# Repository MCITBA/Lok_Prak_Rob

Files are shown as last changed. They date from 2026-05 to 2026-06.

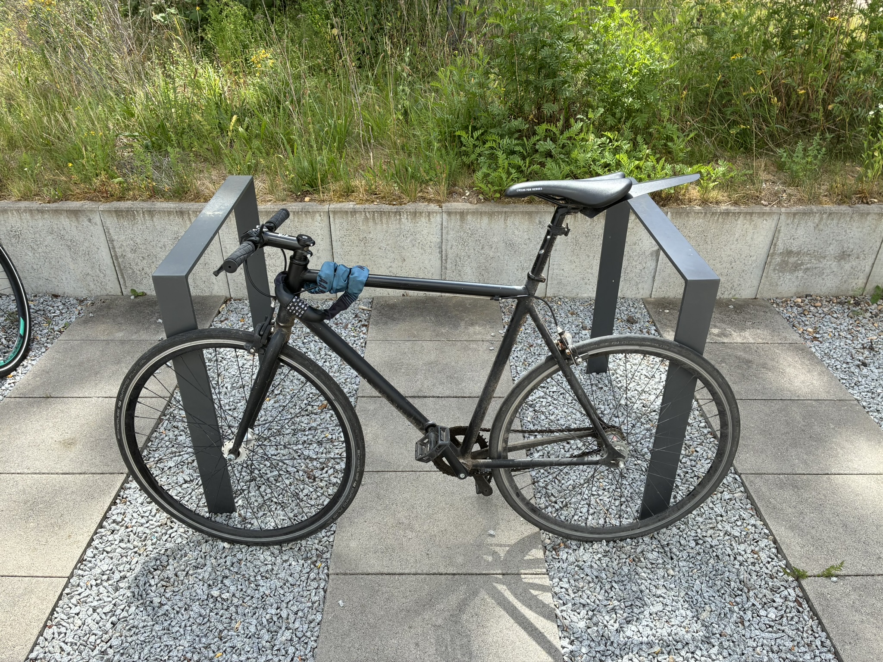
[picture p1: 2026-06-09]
iCloud Fotos/IMG_4484.JPEG

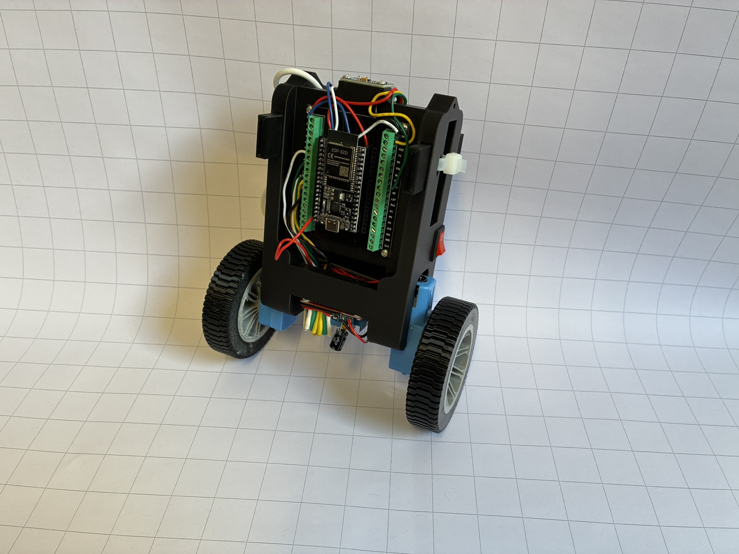
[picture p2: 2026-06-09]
iCloud Fotos/IMG_4480.JPEG

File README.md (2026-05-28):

Werte von KP KI KD  
Text: https://www.overleaf.com/project/6a01d511ccd4f65ef6ab566e  
neuste code version ist: balancing_robot_motors.ino  
Code der potentiel falsche nachrichten foramte der MPU filtert: balance_robot_MPU_fehler  
Sachen die ich brauche:  
u-kürzel, m-nummer  
Name des Fill Material  
foto von: TT-motor, Batterie, Hülle, Rädern, Schalter  
Welche Überstzung beim Motor  
Eckdaten der Baterrie: Volt, A, Ah

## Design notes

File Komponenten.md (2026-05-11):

MPU-6500 (ähnlich zum MPU-6050)
    https://randomnerdtutorials.com/esp32-mpu-6050-accelerometer-gyroscope-arduino/?utm_source=chatgpt.com

    https://github.com/libdriver/mpu6500/blob/main/README_de.md

    https://www.elektronik-kompendium.de/sites/praxis/bauteil_mpu6050-imu.htm

L298N 
    https://randomnerdtutorials.com/esp32-dc-motor-l298n-motor-driver-control-speed-direction/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

Kommunikation
    https://randomnerdtutorials.com/esp32-bluetooth-low-energy-ble-arduino-ide/?utm_source=chatgpt.com

    https://randomnerdtutorials.com/esp32-bluetooth-guide/?utm_source=chatgpt.com

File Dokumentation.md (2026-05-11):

# Ziele / Aufgabe
- Ein Roboter der auf nur zwei Rädern fährt und sich selbstständig aufrecht hält
    - hierfür wird ein PID-Regler verwendet
    - Daten liefert der MPU-6500
- Kommunikation mit einem Handy ermöglichen
    - BLE + entsprechende
    - Austausch von Sensordaten
    - Einstellung der PID-Parameter
        - einfaches Einstellen und Anpassen übers Handy
    - Vorgabe des Soll-Winkels
    - Lenkeinschlag
- Ermöglichen einer Lenkung
    - Ansteuerung ebenfalls über das Smartphone
    - Idee:
        - Soll-PWM für Motor wird "aufgeteilt"
        - prozentual, je nachdem wie stark gelenkt werden soll
- Zusätzliche Herausforderungen
    - wie kann sichergestellt werden, dass der Roboter auch gerade fährt?
        - Verwendung der Beschleunigungswerte?

# Warum haben wir welche Komponenten ausgewählt
## alte Powerbank
- 10.000 mAh
- Output: 2.1 A bei 5V

## ESP32D
- hat bereits eine Antenne verbaut
- ausreichend hohe Taktrate für die Regelung
- läuft auf 5V - passt also zu unserer Powerbank
- Verwendung eines Entwicklungsboards, um den ESP32 am Roboter zu befestigen

## TT-Motor
- ein Motor pro Rad, damit wir lenken können
- müssen für 3V ausgelegt sein (siehe Motortreiber)
- haben bereits ein Getriebe integriert, das ist notwendig um die drehzahl zu verringern

## Motortreiber - L298N
- I2C kompatibel
- Zur Steuerung der Drehgeschwindigkeit und **Drehrichtung**  <--wichtig!
    - H-Brücke
- kann zwei Motoren gleichzeitig ansteuern
- funktioniert auch noch bei 5V *untere Grenze!*
    - Logische Spannung bei 5V und dann über Jumper auch Antriebsspannung
    - interner Spannungsabfall von ca. 2 V (Spannungsabfall an den Transistoren der doppel H-Brücke)

## Gyroskop und Beschleunigungssensor - MPU-6500
- I2C kompatibel
- je drei Achsen
- für 3 bis 5V ausgelegt
- kleines Modul zur Bestimmung der Beschleunigung und der Verdrehung

## Zusätzliche Komponenten
- Schalter
- - gesamten Roboter an/aus schalten
- Smartphone zur Kommunikation 
    - Vorgaben des Sollwinkels
    - Einstellen der Regelparameter 
    - Lenken

## Zusammenfassung
- alle Komponenten laufen mit 5V
- Kommunikation über I2C möglich

# Schaltkreis
- optionale Kondensatoren hinzugefügt

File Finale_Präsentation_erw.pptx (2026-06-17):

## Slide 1

Name - Title of Presentation

The new PowerPoint Slide library is here!
Modern design, many targeted layouts, easy to use.
The new template offers many options for creating presentations with a uniform and modern look.
The following slides offer an ideal basis for beautifully designed presentations. Simply copy complete slides or individual elements from this file.
As of April 23, 2025
The images included are placeholders

## Slide library

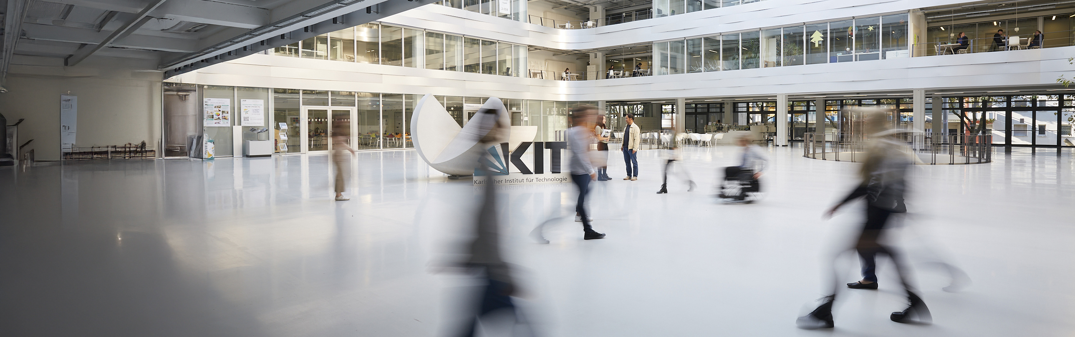
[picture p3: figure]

Designed slides and elements for
easy creation of presentations.

## Design Elements

Highlight Boxes

Lines

Text box

Standard text box
with bullet point

Highlight Box

Highlight Box

Standard Box

Standard Box

Standard text box
with bullet point

Highlight Box

Highlight Box

© Image source top

Highlight Box

1

1

© Image source bottom

Source: I am a dummy text. And I've always been a dummy text

## Design Elements - Pictograms

## Title of the Presentation

Name, Date

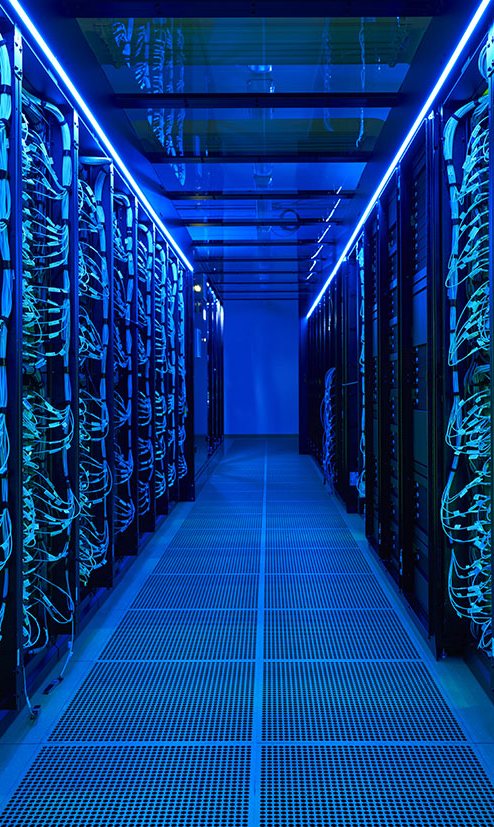
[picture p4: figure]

Placeholder

## Title of the Presentation

Name, Date

Placeholder

## Title of the Presentation

Name, Date

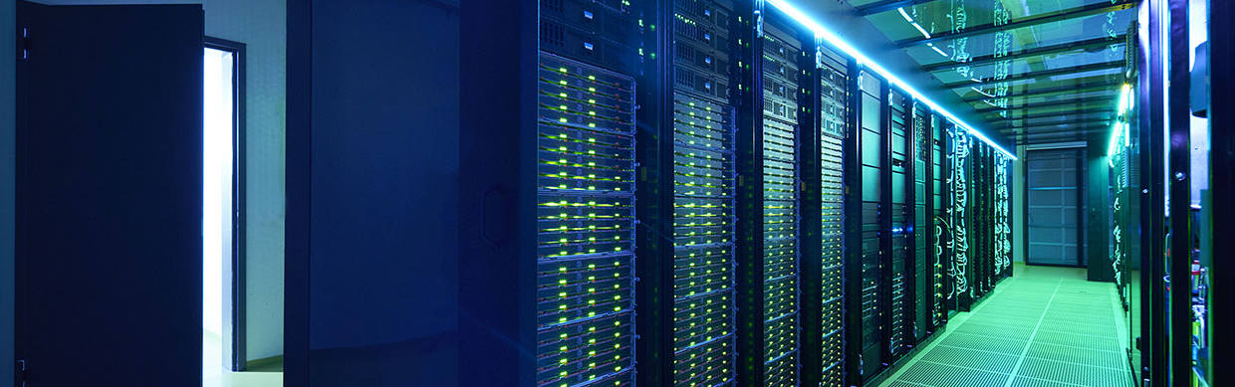
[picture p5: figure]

Placeholder

## Title of the Presentation

Name, Date

Placeholder

## Slide Title

          - I am a dummy copy. And I’ve been a dummy copy since my birth.
- It took me a long time to realize what it means to be a dummy copy: you make no sense. You stand out now and then by being completely out of context.
  - But does that make me a bad copy?
  - I know that I’ll never stand a chance of appearing in the Economist
  - But does that make me any less important? I’m a dummy! But I enjoy being a copy.

## Slide Title

          - I am a dummy copy. And I’ve been a dummy copy since my birth.
- It took me a long time to realize what it means to be a dummy copy: you make no sense. You stand out now and then by being completely out of context.
  - But does that make me a bad copy?
  - I know that I’ll never stand a chance of appearing in the Economist
  - But does that make me any less important? I’m a dummy! But I enjoy being a copy.

          - I am a dummy copy. And I’ve been a dummy copy since my birth.
- It took me a long time to realize what it means to be a dummy copy: you make no sense. You stand out now and then by being completely out of context.
  - But does that make me a bad copy?
  - I know that I’ll never stand a chance of appearing in the Economist
  - But does that make me any less important? I’m a dummy! But I enjoy being a copy.
      - But does that make me any less important? I’m a dummy! But I enjoy being a copy
      - But does that make me any less important? I’m a dummy! But I enjoy being a copy

## Slide Title

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

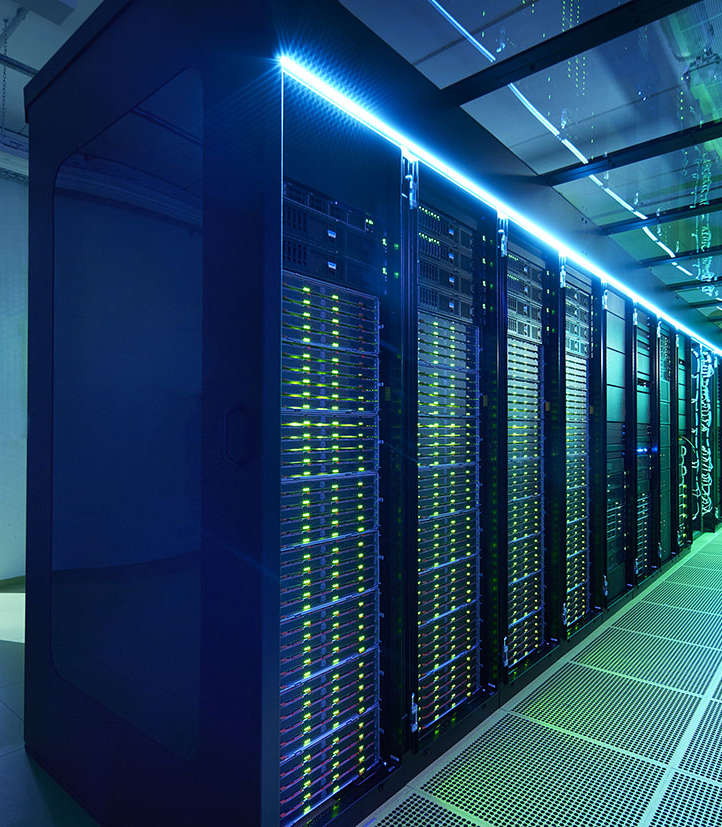
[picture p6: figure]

Placeholder

## Slide Title

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

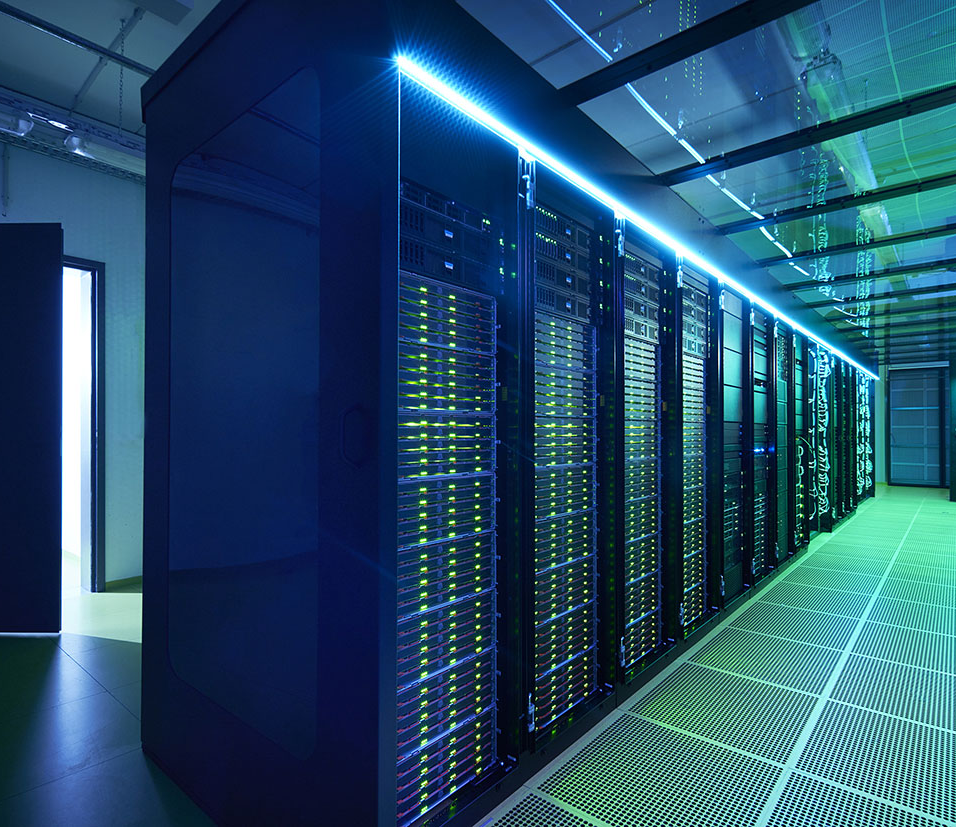
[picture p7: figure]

Placeholder

## Slide Title

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

Placeholder

## Slide Title

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

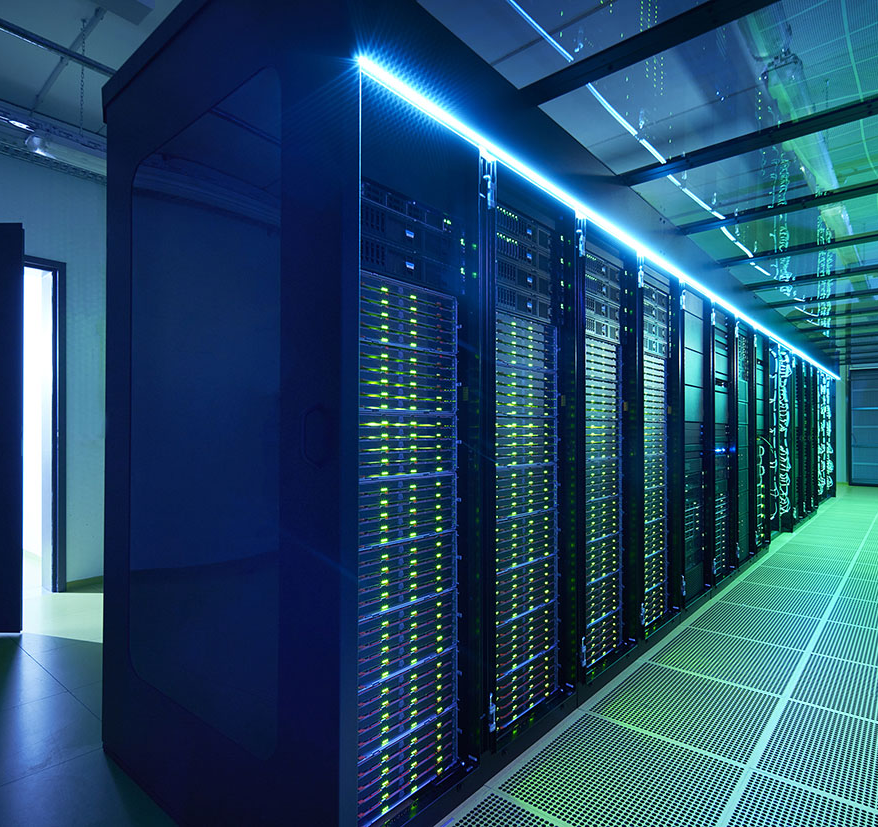
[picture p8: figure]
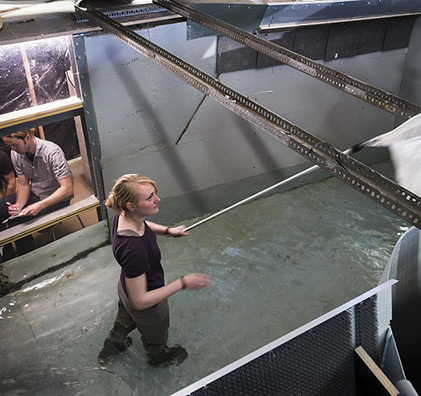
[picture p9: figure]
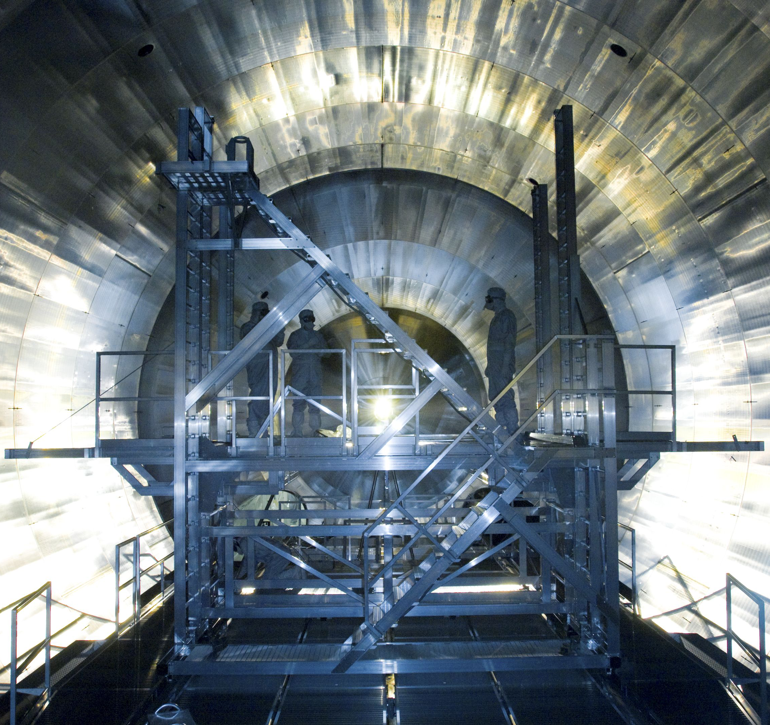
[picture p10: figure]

Placeholder

## Slide Title

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

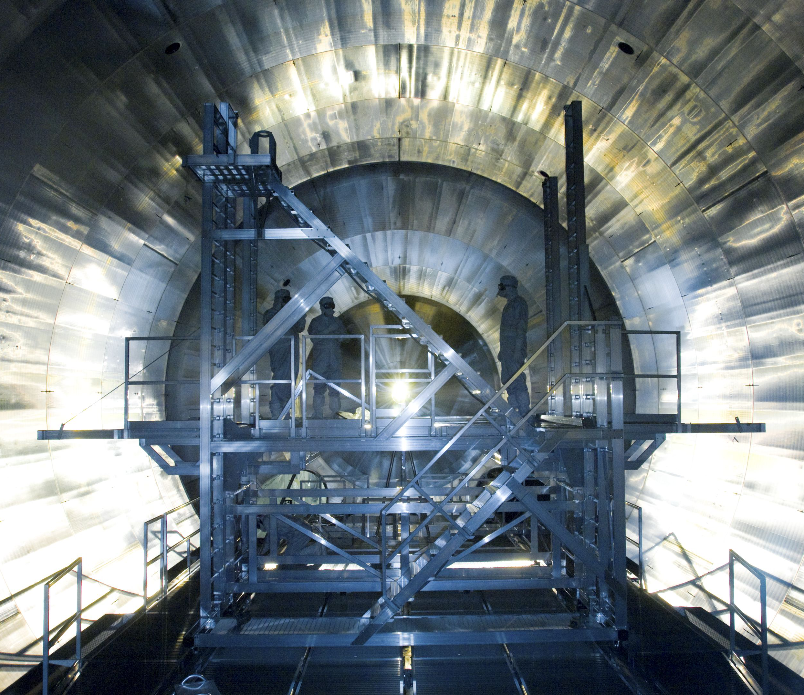
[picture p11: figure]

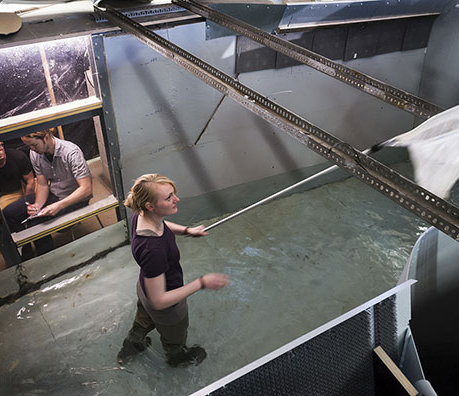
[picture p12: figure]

Placeholder

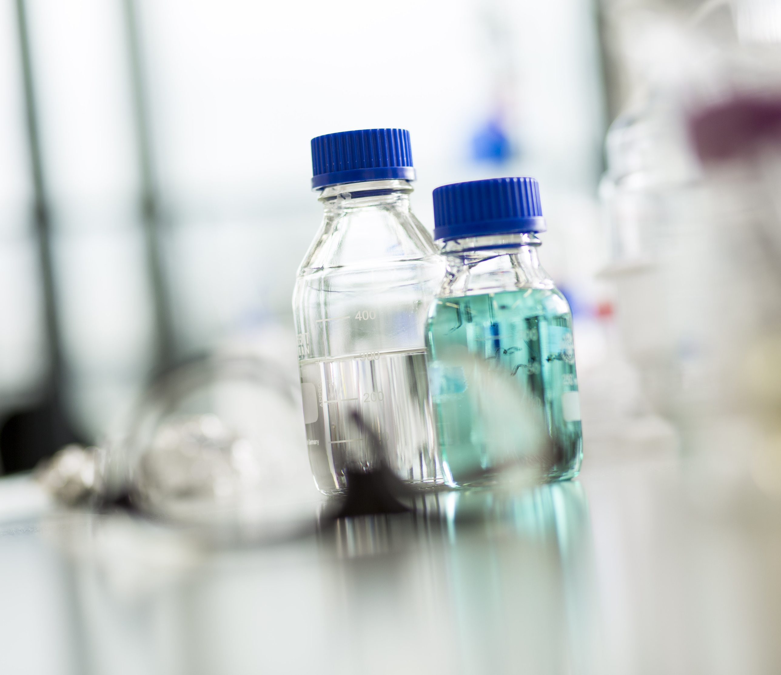
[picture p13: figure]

## Slide Title

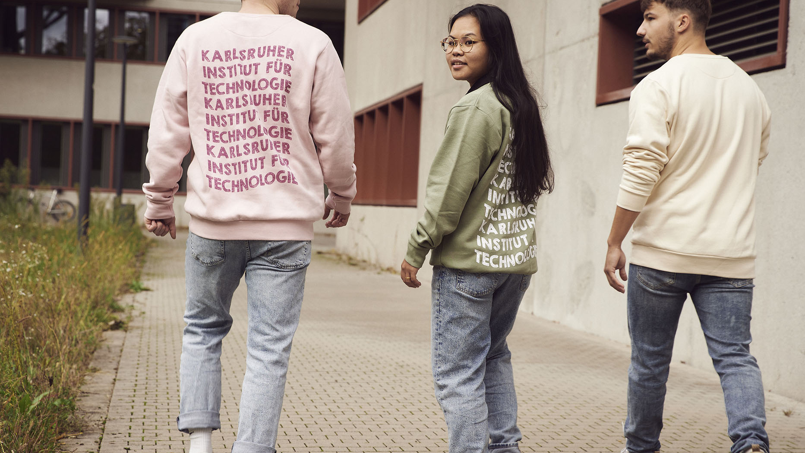
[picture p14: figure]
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

Placeholder

## Slide Title

Source: I am a dummy text. And I've always been a dummy text

## Slide Title

Source: I am a dummy text. And I've always been a dummy text

## Slide Title

Source: I am a dummy text. And I've always been a dummy text

## Slide Title

Source: I am a dummy text. And I've always been a dummy text

## Slide Title

Source: I am a dummy text. And I've always been a dummy text

## Slide Title

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

Source: I am a dummy text. And I've always been a dummy text

## Slide Title

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

Source: I am a dummy text. And I've always been a dummy text

Market shares
65,8 %

## Tables

- After filling the table, it can make sense to highlight important content.
- The best way to do this is to color individual cells, columns or rows.
- Text on colored cells must always be colored white. Totals can be highlighted with a colored line and colored, bold font.

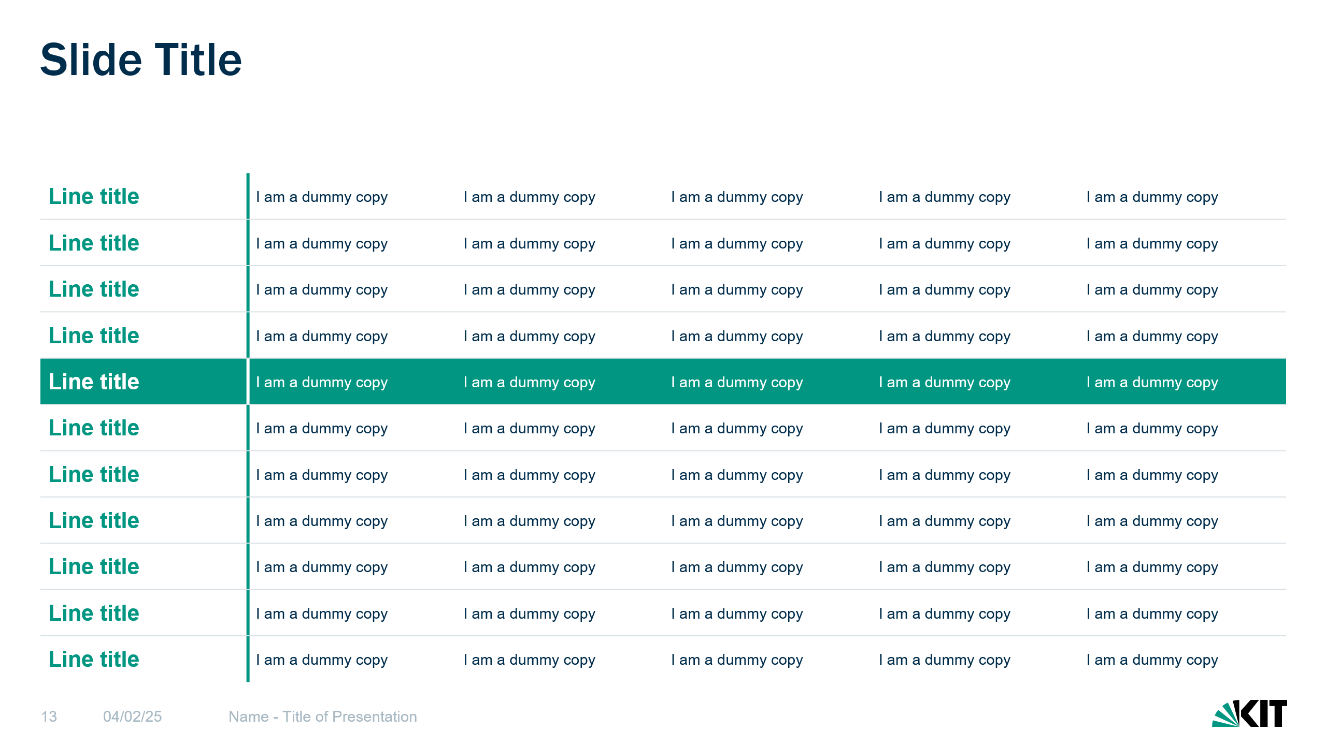
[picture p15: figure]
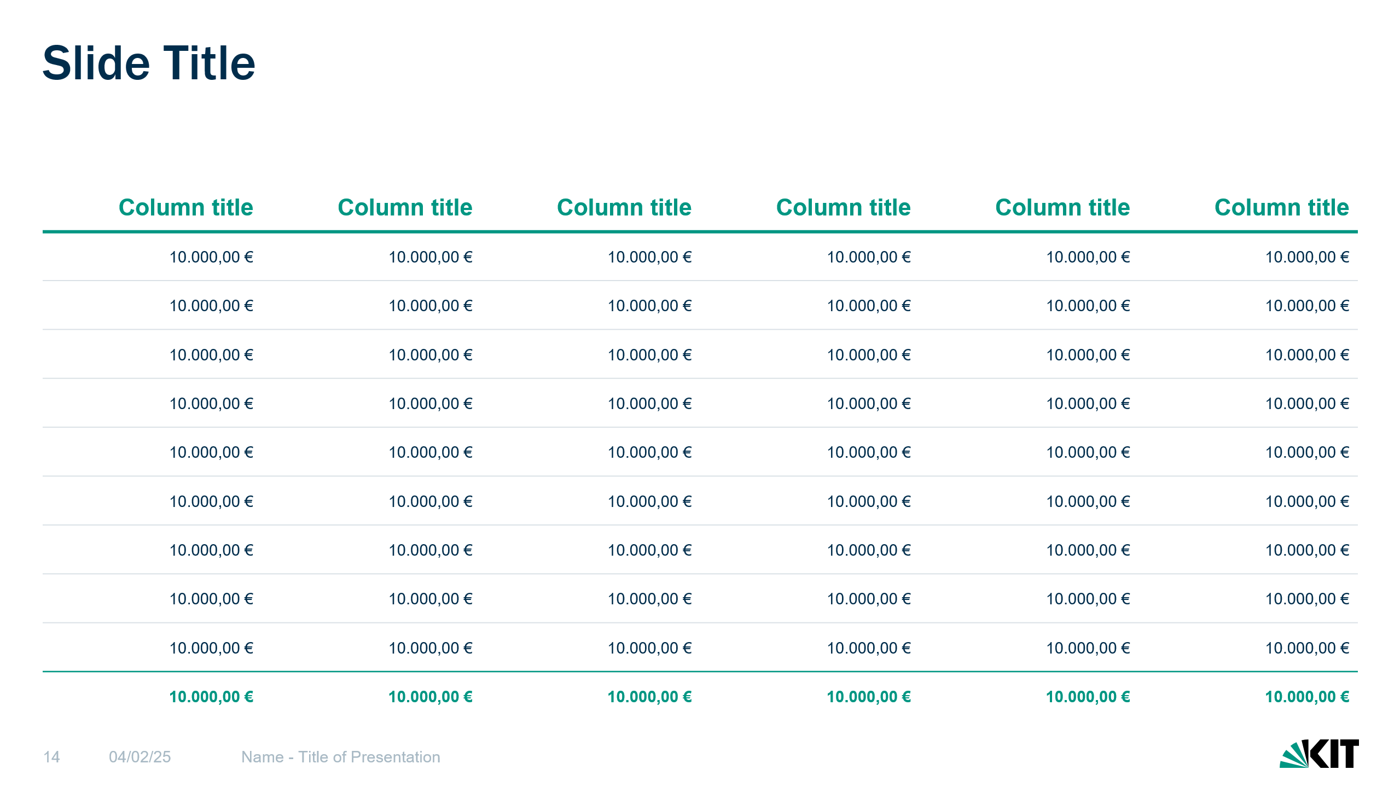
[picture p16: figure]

## Slide Title

Column title | Column title | Column title | Column title | Column title | Column title
I am a dummy copy | I am a dummy copy | I am a dummy copy | I am a dummy copy | I am a dummy copy | I am a dummy copy
I am a dummy copy | I am a dummy copy | I am a dummy copy | I am a dummy copy | I am a dummy copy | I am a dummy copy
I am a dummy copy | I am a dummy copy | I am a dummy copy | I am a dummy copy | I am a dummy copy | I am a dummy copy
I am a dummy copy | I am a dummy copy | I am a dummy copy | I am a dummy copy | I am a dummy copy | I am a dummy copy
I am a dummy copy | I am a dummy copy | I am a dummy copy | I am a dummy copy | I am a dummy copy | I am a dummy copy
I am a dummy copy | I am a dummy copy | I am a dummy copy | I am a dummy copy | I am a dummy copy | I am a dummy copy
I am a dummy copy | I am a dummy copy | I am a dummy copy | I am a dummy copy | I am a dummy copy | I am a dummy copy
I am a dummy copy | I am a dummy copy | I am a dummy copy | I am a dummy copy | I am a dummy copy | I am a dummy copy
I am a dummy copy | I am a dummy copy | I am a dummy copy | I am a dummy copy | I am a dummy copy | I am a dummy copy
I am a dummy copy | I am a dummy copy | I am a dummy copy | I am a dummy copy | I am a dummy copy | I am a dummy copy

## Slide Title

Line title | I am a dummy copy | I am a dummy copy | I am a dummy copy | I am a dummy copy | I am a dummy copy
Line title | I am a dummy copy | I am a dummy copy | I am a dummy copy | I am a dummy copy | I am a dummy copy
Line title | I am a dummy copy | I am a dummy copy | I am a dummy copy | I am a dummy copy | I am a dummy copy
Line title | I am a dummy copy | I am a dummy copy | I am a dummy copy | I am a dummy copy | I am a dummy copy
Line title | I am a dummy copy | I am a dummy copy | I am a dummy copy | I am a dummy copy | I am a dummy copy
Line title | I am a dummy copy | I am a dummy copy | I am a dummy copy | I am a dummy copy | I am a dummy copy
Line title | I am a dummy copy | I am a dummy copy | I am a dummy copy | I am a dummy copy | I am a dummy copy
Line title | I am a dummy copy | I am a dummy copy | I am a dummy copy | I am a dummy copy | I am a dummy copy
Line title | I am a dummy copy | I am a dummy copy | I am a dummy copy | I am a dummy copy | I am a dummy copy
Line title | I am a dummy copy | I am a dummy copy | I am a dummy copy | I am a dummy copy | I am a dummy copy
Line title | I am a dummy copy | I am a dummy copy | I am a dummy copy | I am a dummy copy | I am a dummy copy

## Slide Title

Column title | Column title | Column title | Column title | Column title | Column title
10.000,00 € | 10.000,00 € | 10.000,00 € | 10.000,00 € | 10.000,00 € | 10.000,00 €
10.000,00 € | 10.000,00 € | 10.000,00 € | 10.000,00 € | 10.000,00 € | 10.000,00 €
10.000,00 € | 10.000,00 € | 10.000,00 € | 10.000,00 € | 10.000,00 € | 10.000,00 €
10.000,00 € | 10.000,00 € | 10.000,00 € | 10.000,00 € | 10.000,00 € | 10.000,00 €
10.000,00 € | 10.000,00 € | 10.000,00 € | 10.000,00 € | 10.000,00 € | 10.000,00 €
10.000,00 € | 10.000,00 € | 10.000,00 € | 10.000,00 € | 10.000,00 € | 10.000,00 €
10.000,00 € | 10.000,00 € | 10.000,00 € | 10.000,00 € | 10.000,00 € | 10.000,00 €
10.000,00 € | 10.000,00 € | 10.000,00 € | 10.000,00 € | 10.000,00 € | 10.000,00 €
10.000,00 € | 10.000,00 € | 10.000,00 € | 10.000,00 € | 10.000,00 € | 10.000,00 €
10.000,00 € | 10.000,00 € | 10.000,00 € | 10.000,00 € | 10.000,00 € | 10.000,00 €

## Slide Title

Step 1
I am a dummy copy. And I’ve been a dummy copy since my birth.
It took me a long time to realize what it means to be a dummy copy: you make no sense. You stand out now and then by being completely out of context.

Step 2
I am a dummy copy. And I’ve been a dummy copy since my birth.
It took me a long time to realize what it means to be a dummy copy: you make no sense. You stand out now and then by being completely out of context.

Step 3
I am a dummy copy. And I’ve been a dummy copy since my birth.
It took me a long time to realize what it means to be a dummy copy: you make no sense. You stand out now and then by being completely out of context.

## Slide Title

Step 1
I am a dummy copy.
It took me a long time to realize what it means to be a dummy copy: you make no sense. You stand out now and then by being completely out of context.

Step 2
I am a dummy copy.
It took me a long time to realize what it means to be a dummy copy: you make no sense. You stand out now and then by being completely out of context.

Step 3
I am a dummy copy.
It took me a long time to realize what it means to be a dummy copy: you make no sense. You stand out now and then by being completely out of context.

Step 4
I am a dummy copy.
It took me a long time to realize what it means to be a dummy copy: you make no sense. You stand out now and then by being completely out of context.

## Slide Title

Step 1
I am a dummy copy.
It took me a long time to realize what it means to be a dummy copy.

Step 2
I am a dummy copy.
It took me a long time to realize what it means to be a dummy copy.

Step 3
I am a dummy copy.
It took me a long time to realize what it means to be a dummy copy.

Step 4
I am a dummy copy.
It took me a long time to realize what it means to be a dummy copy.

Step 5
I am a dummy copy.
It took me a long time to realize what it means to be a dummy copy.

Step 6
I am a dummy copy.
It took me a long time to realize what it means to be a dummy copy.

## Slide Title

Step 1
I am a dummy copy. And I’ve been a dummy copy since my birth.

Step 2
I am a dummy copy. And I’ve been a dummy copy since my birth.

Step 3
I am a dummy copy. And I’ve been a dummy copy since my birth.

Step 4
I am a dummy copy. And I’ve been a dummy copy since my birth.

Step 5
I am a dummy copy. And I’ve been a dummy copy since my birth.

Step 6
I am a dummy copy. And I’ve been a dummy copy since my birth.

Step 7
I am a dummy copy. And I’ve been a dummy copy since my birth.

Step 8
I am a dummy copy. And I’ve been a dummy copy since my birth.

## Slide Title

33 %
I am a dummy copy. And I’ve been a dummy copy since
my birth.

33 %
I am a dummy copy. And I’ve been a dummy copy since
my birth.

33 %
I am a dummy copy. And I’ve been a dummy copy since
my birth.

33 %
I am a dummy copy. And I’ve been a dummy copy since
my birth.

## Slide Title

I am a dummy copy. And I’ve been
a dummy copy since my birth.

I am a dummy copy. And I’ve been
a dummy copy since my birth.

I am a dummy copy.
And I’ve been a dummy
copy since my birth.

dummy copy

I am a dummy copy.
And I’ve been a dummy
copy since my birth.

I am a dummy copy. And I’ve been
a dummy copy since my birth.

I am a dummy copy. And I’ve been
a dummy copy since my birth.

## Slide Title

January
2025

February
2025

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

March –
May 2025

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

June –
July 2025

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

August –
October 2025

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

November – December 2025

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

## Slide Title

| CW 1 | CW 2 | CW 3 | CW 4 | CW 5 | CW 6 | CW 7 | CW 8 | CW 8 | CW 10 | CW 11 | CW 12
Dummy copy
Dummy copy
Dummy copy
Dummy copy
Dummy copy
Dummy copy
Dummy copy
Dummy copy
Dummy copy
Dummy copy

Legend

Legend

Legend

## Slide Title

Name
Position, title or function

Name
Position, title or function

Name
Position, title or function

Name
Position, title or function

Name
Position, title or function

Name
Position, title or function

Name
Position, title or function

Name
Position, title or function

Name
Position, title or function

Name
Position, title or function

Name
Position, title or function

Name
Position, title or function

Name
Position, title or function

Name
Position, title or function

Name
Position, title or function

Name
Position, title or function

Name
Position, title or function

Name
Position, title or function

Name
Position, title or function

Name
Position, title or function

Name
Position, title or function

Name
Position, title or function

Name
Position, title or function

Name
Position, title or function

## Slide Title

Name

Name

Name

Name
Position, title or function

Name
Position, title or function

Name
Position, title or function

Name
Position, title or function

Name
Position, title or function

Name
Position, title or function

Name
Position, title or function

Name
Position, title or function

Name
Position, title or function

Name
Position, title or function

Name
Position, title or function

Name
Position, title or function

Name
Position, title or function

Name
Position, title or function

Name
Position, title or function

Name
Position, title or function

Name
Position, title or function

Name
Position, title or function

Name
Position, title or function

Name
Position, title or function

Name
Position, title or function

Name
Position, title or function

Name
Position, title or function

Name
Position, title or function

Name
Position, title or function

Name
Position, title or function

Name
Position, title or function

Name
Position, title or function

Name
Position, title or function

Name
Position, title or function

Name
Position, title or function

## Slide Title

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

Dummy copy

Dummy copy

Dummy copy

Karlsruhe

Dummy copy

Dummy copy

Dummy copy

Karlsruhe

## Contact

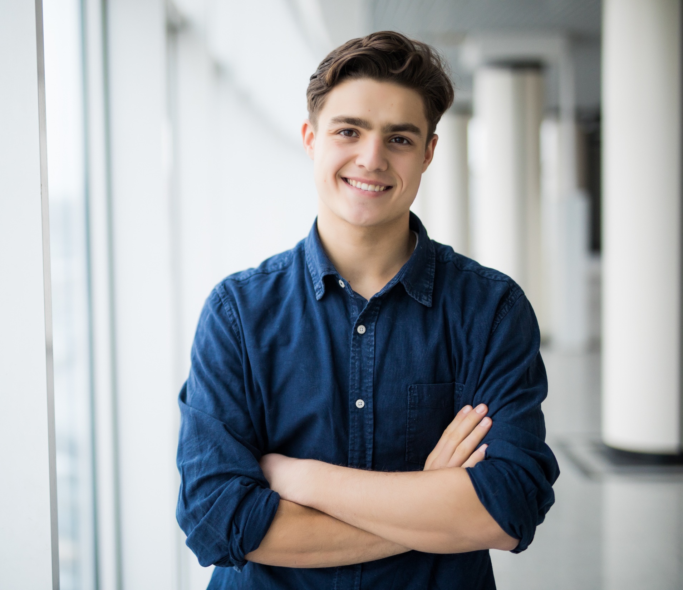
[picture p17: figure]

Placeholder

- Name
- Position, title or function
- +49 000 1234567
- info@kit.edu
- Karlsruher Institut für Technologie
- Kaiserstraße 12 76131 Karlsruhe Germany

## Team

- Name
- Position, title or function

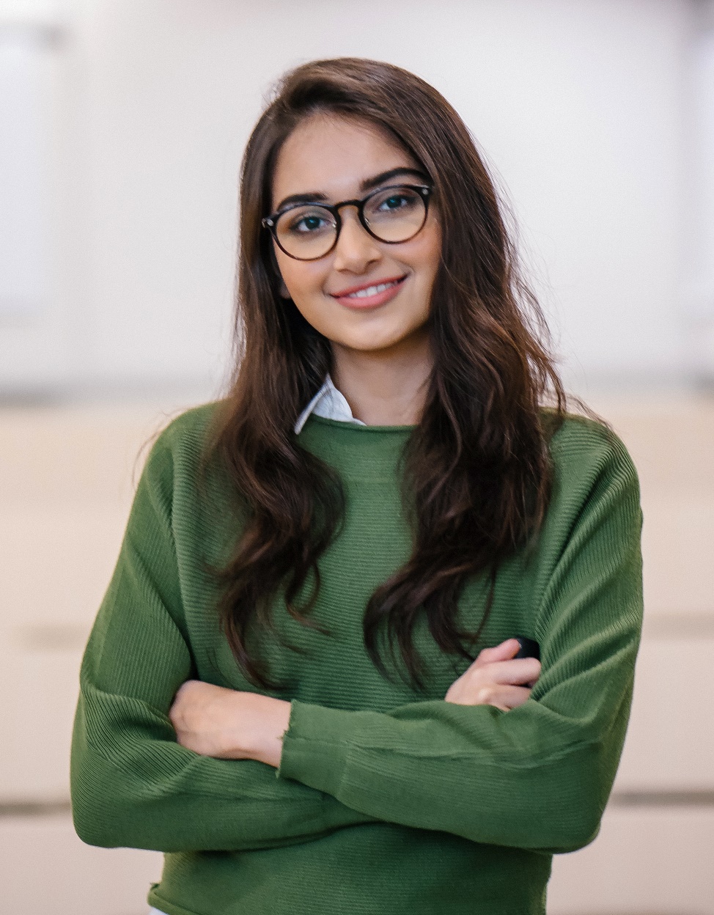
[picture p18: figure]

- Name
- Position, title or function

- Name
- Position, title or function

- Name
- Position, title or function

Placeholder

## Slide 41

## Selbstbalancierender Roboter

Jan Fritze
Marius Carrier

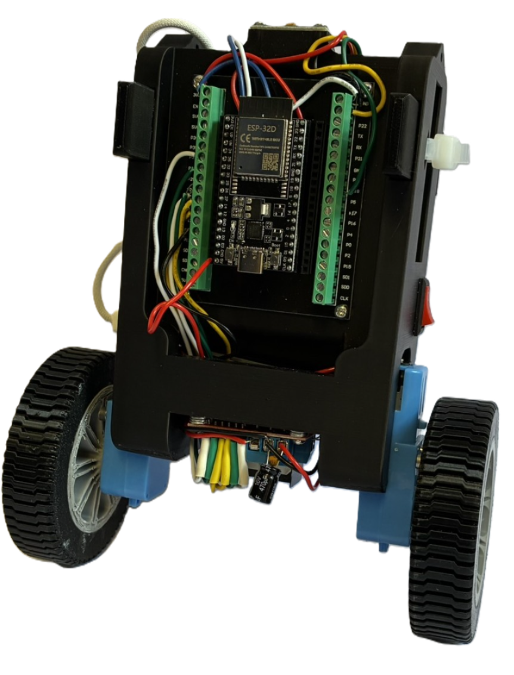
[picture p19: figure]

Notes: Der Roboter verhält sich wie ein inverses Pendel. Da sein Schwerpunkt oberhalb der Radachse liegt, würde er ohne aktive Regelung umfallen.
Deshalb muss eine erkannte Neigung unmittelbar durch eine passende Radbewegung ausgeglichen werden.
Kippt der Roboter nach vorne oder hinten, erkennt der Roboter diese Bewegung und berechnet daraus ein Motorsignal, sodass die Räder in Richtung der Kippbewegung fahren.
Dadurch wird der Aufstandspunkt unter den Schwerpunkt verschoben und der Roboter kann sich wieder aufrichten

## Gliederung

- Aufbau und technische Umsetzung
  - Komponentenauswahl
  - Schaltplan
1. Programmierung
  - IMU
  - Regelkreis
  - Motorsteuerung
  - Live-Tuning
- Ergebnisse
- Ausblick

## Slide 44

M. Carrier J. Fritze – Selbstbalancierender Roboter

Aufbau und technische Umsetzung

## Komponentenauswahl

- ESP32D als zentrale Steuereinheit
  - Ausreichende Rechenleistung und integriertes WLAN
- MPU-6500 zur Winkelmessung
  - Misst Beschleunigung und Winkelgeschwindigkeit
L298N-Motortreiber
  - Ermöglicht die Ansteuerung der Motoren, da der ESP32D die benötigten Motorströme nicht direkt liefern kann
  - H-Brücke ermöglicht Umpolarisierung der Motorenspannung
- Motoren
  - Motoren mit 90:1-Übersetzung für niedrigere Drehzahl

Bauteile
ESP32D
TT-Motor
MPU-6500
L298N
Powerbank
NTC 5D-7
Schalter
ELKO 470
104 Keramikkondensator
PD-Trigger

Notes: Hier seht ihr eine List aller Elektrischen Bauteile
Wir werdend jetzt im laufe der Präsentation, der Grund für die Auswahl der Komponenten sowie deren Wirkung erklären
Anfangen tue ich mit dem prinzipiellen Aufbau
ESP32D ist wie das ESP32 nur das es bereits eine integrierte Antenne hat.
Das haben wir ausgewählt, weil der eigentliche Steuerungsalgorithmus, nicht sonderlich komplex ist
Jedoch brauchen wir die WLAN-Funktion wie wir später zeigen werden
Um kippen zu registrieren nutzen wir den MPU-6500
Die L298N ist sehr wichtig, für die Nutzung der Motoren, da weder kann die ESP32D die nötigen Motorströme liefern, um die Motoren anzutreiben, noch könnte er die Spannung umpolarisieren um die Richtung der Motoren zu wechseln
Für die Motoren haben wir uns für Motoren mit einer Übersetzung von 90:1 entschieden, was uns eine feine Regulierung der Umdrehungen erlaubt

## Das Konzept

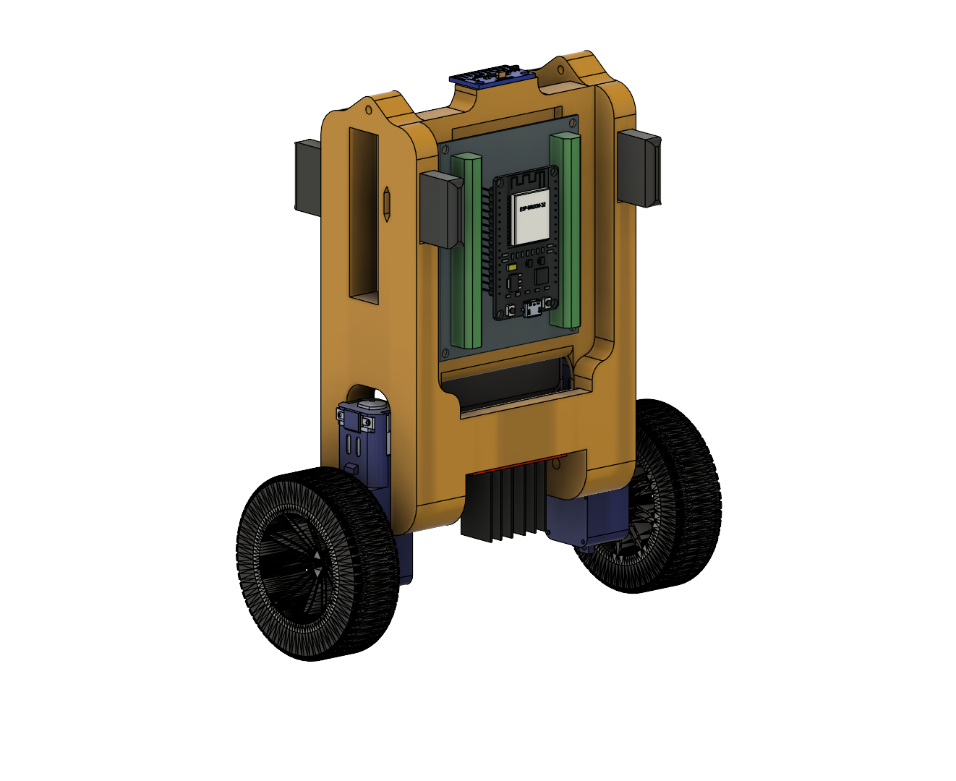
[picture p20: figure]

## Schaltplan und Energieversorgung

- Powerbank als Spannungsquelle
  - Kann 5 oder 9 Volt liefern
  - PD-Trigger fordert 9 Volt an
- L298N als zentraler Leistungsknoten
  - Zwei Spannungslevel
      - Interner Spannungsregler: 5 V für Logik
      - 9 V direkt für Motoren
ESP32 über 5 V Ausgang des L298N
    - Gemeinsame Masse
MPU-6500
    - Über 3,3 V des ESP32 versorgt
Platzsparendes Design
  - Kombination aus Spannungswandler und Motoransteuerung
  - Verzicht auf Step Down Converter

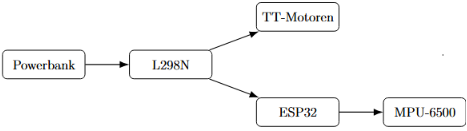
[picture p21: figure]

## Schaltplan und Energieversorgung

Kondensatoren zur Spannungsstabilisierung
  - 100-nF Keramikkondensator:
        - Kompensiert hochfrequente Störungen
    - 470-µF Elektrolytkondensator:
      - Gleicht kurzzeitige Spannungseinbrüche bei Laständerungen aus
Problem mit Kondensatoren
  - Kondensatoren beim Einschalten zunächst ungeladen
  - Verhält sich kurzzeitig wie ein Kurzschluss
  - Hoher Einschaltstrom
NTC zur Begrenzung des Einschaltstroms
  - NTC 5D-7 in kaltem Zustand Nominalwiderstand von 5 Ohm
  - Erwärmt sich nach dem Einschalten
      - Widerstand sinkt stark ab → geringer Spannungsabfall während des Betriebs
Robusterer Betrieb
  - Verringern Risiko von Spannungseinbrüchen und Fehlfunktionen des ESP32

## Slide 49

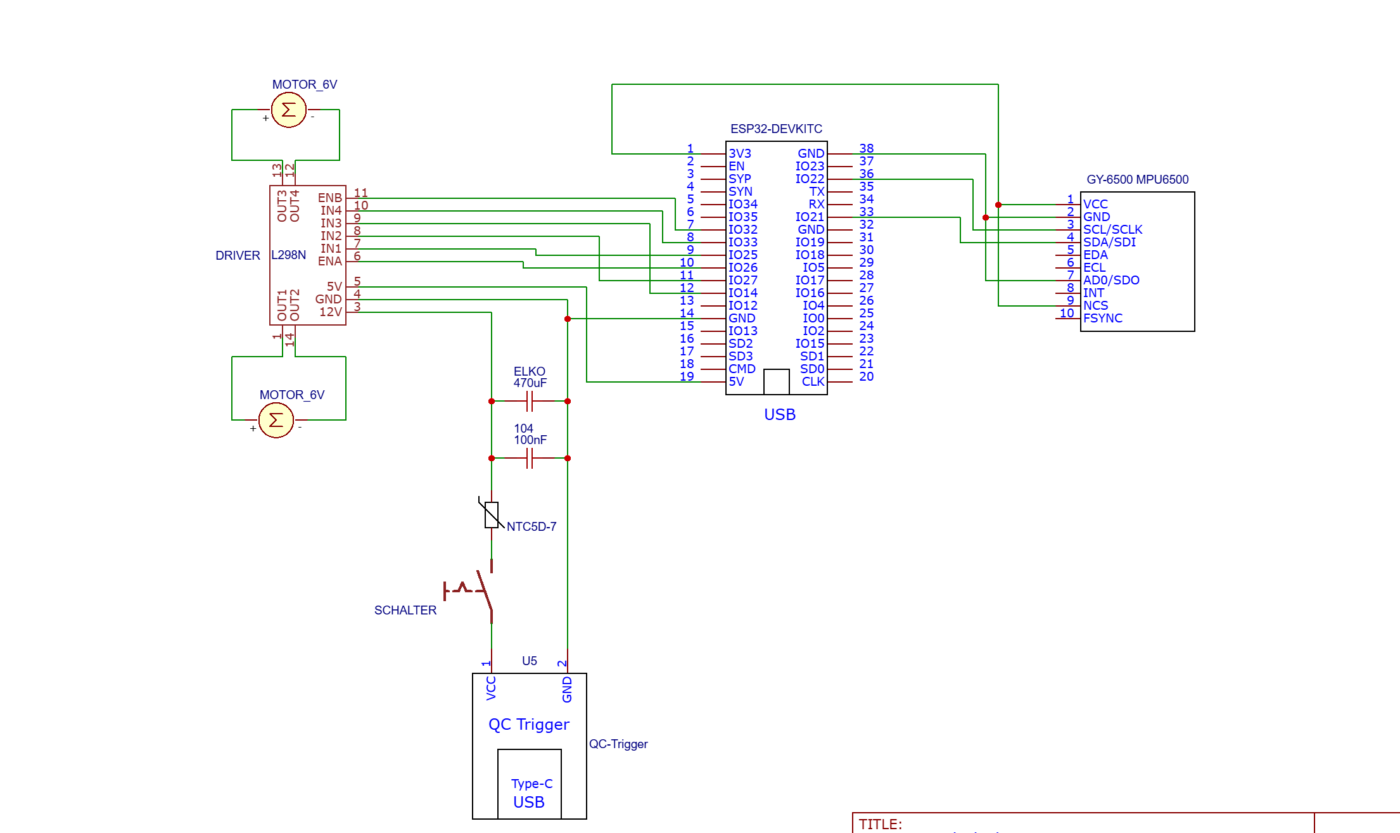
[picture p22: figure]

## Der fertige Roboter

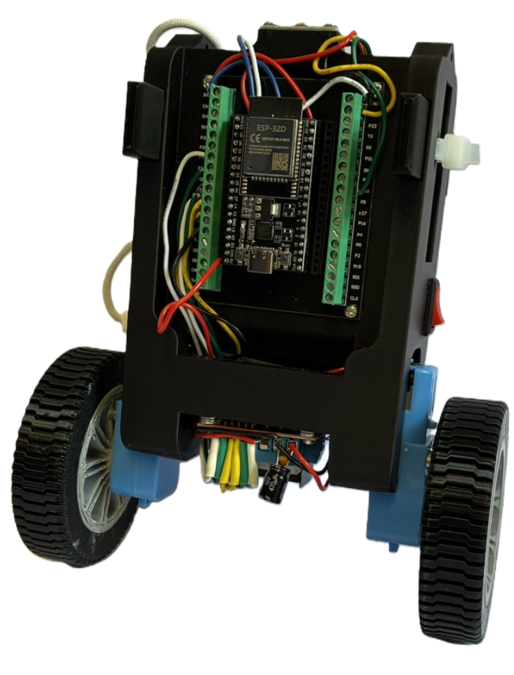
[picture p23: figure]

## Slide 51

M. Carrier J. Fritze -- Selbstbalancierender Roboter

Programmierung

## Programmierung

          - Messung und Kalibrierung des Neigungswinkels
  - Der MPU-6500 erfasst dafür Beschleunigung und Winkelgeschwindigkeit.
  - Der Beschleunigungssensor liefert einen stabilen Referenzwinkel, reagiert aber empfindlich auf Vibrationen und Bewegungen.
  - Das Gyroskop erkennt schnelle Winkeländerungen, ist jedoch langfristig driftanfällig.
  - Ein Komplementärfilter kombiniert beide Signale zu einem schnellen und stabilen Winkelwert.
  - Vor dem Regelbetrieb wird das Gyroskop mit 500 Messungen kalibriert.
  - Tiefpassfilter um Rauschen zu minimieren

M. Carrier J. Fritze – Selbstbalancierender Roboter

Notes: Der Beschleunigungssensor misst die Beschleunigung des Roboters und kann dadurch die Richtung der Erdbeschleunigung erfassen.
Aus dieser Richtung lässt sich ein Neigungswinkel berechnen.
Dieser Winkel ist langfristig stabil, wird jedoch durch Bewegungen, Vibrationen und Beschleunigungen des Roboters gestört.
Das Gyroskop misst dagegen die Winkelgeschwindigkeit.
Durch Integration dieser Winkelgeschwindigkeit über die Zeit kann die Änderung des Winkels sehr schnell erfasst werden.
Dieser Wert eignet sich daher besonders gut für schnelle Bewegungen.
Gyroskops hat jedoch Drift.
Kleine Messfehler werden bei der Integration über die Zeit aufsummiert, wodurch der berechnete Winkel langsam vom tatsächlichen Winkel abweicht.
Komplementärfilter:
Winkel überwiegend aus der Winkelgeschwindigkeit des Gyroskops berechnet und durch den Winkel aus dem Beschleunigungssensor korrigiert.
Der Gyroskopanteil sorgt somit für eine schnelle Reaktion, während der Beschleunigungssensor den Winkel langfristig stabilisiert.
Vor dem Regelbetrieb wird das Gyroskop kalibriert.
Dafür muss der Roboter beim Einschalten ruhig gehalten werden.
Während der Kalibrierung werden 500 Messwerte aufgenommen und gemittelt, um so den Gyroskop-Offset zu bestimmt.
Dieser Offset beschreibt den Messfehler des Gyroskops im ruhenden Zustand und wird anschließend von den weiteren Messwerten abgezogen.
Winkelgeschwindigkeit wird außerdem tiefpassgefiltert, um Messrauschen und schnelle Sprünge im Signal zu reduzieren.

## Programmierung

          - Berechnung der Stellgröße mit dem PID-Regler
  - Grundlage ist der Regelfehler zwischen Sollwinkel und gemessenem Istwinkel.
  - Der PID-Regler setzt sich aus drei Anteilen zusammen: Rückstellung, Korrektur bleibender Abweichungen und Dämpfung schneller Bewegungen.
  - Bei größeren Winkelfehlern wird der P-Anteil ab 7° zusätzlich progressiv verstärkt.
  - So reagiert der Roboter bei kleinen Auslenkungen weich, bei kritischen Schieflagen aber deutlich stärker.
  - Die Stellgröße wird abschließend auf den zulässigen PWM-Bereich begrenzt.

M. Carrier J. Fritze – Selbstbalancierender Roboter

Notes: Zur Regelung nutzen wir einen PID-Regler
Unser Eingangswert ist die Istwinkel und user Fehler ist die Differenz zwischen Soll und Ist winkel
Um die Anteile nochmal zu überfliegen, haben wir hier den linearen Rückstellungswert, Korrektur bleibender Abweichungen und Dämpfung schneller Bewegungen.
Da das Kippmoment des Roboters jedoch nicht, linear ist, haben wir ab 7° ebenfalls einen nicht linearen Korrektur Term eingesetzt.
Dies erlaubt uns bei kleinen Auslenkung fein zu justieren während wir gleichzeitig bei großen Auslenkung, große Korrektur Möglichkeiten haben
Damit die Ergebnisse im Definiertenbereich bleiben, wird die Ausgabe des PWM-Reglers auf -/+ 25 beschränkt

## Programmierung

          - Einfluss der Regelungsfrequenz und PWM-Frequenz
Regelkreis – 200 Hz (berechnet alle 5 ms einen neuen Motorbefehl)
    - Hohe Regelungsfrequenz ermöglicht schnelle Reaktion
    - Zu hohe Frequenzen
      - verstärken Messrauschen
      - können von Motoren mechanisch nicht sinnvoll umgesetzt werden
PWM-Frequenz – 200 Hz
    - Legt fest, wie schnell das Motorsignal ein- und ausgeschaltet wird
    - Bei 200 Hz entstehen längere Impulse
      - Erleichtern das Anlaufen kleiner Gleichstrommotoren
Wahl der Frequenzen
    - Kompromiss zwischen sicherem Anlauf, ruhigem Motorlauf und hörbarem Motorgeräusch

M. Carrier J. Fritze – Selbstbalancierender Roboter

## Programmierung

- Motoransteuerung - Probleme
- Mechanisches Getriebespiel (Backlash):
- ca. ± 2° Leerlauf um Totpunkt
- kleine Korrektursignale laufen ins Leere
- Hohes Losbrechmoment:
- Hohe innere Reibung
- Motoren laufen erst ab einem PWM-Wert von ca. 80 bis 100 an
- Konsequenz:
- klassische, lineare PID-Regelung versagt im Nahbereich des Nullpunkts
  - Kleine Steuersignale → Motoren bewegen sich nicht

M. Carrier J. Fritze – Selbstbalancierender Roboter

## Programmierung

- Motoransteuerung - Lösungsstrategien
- Maßnahme 1: Stufenförmige Mindest-PWM
- Künstliche Anhebung des minimalen Stellsignals knapp über die Haftreibungsgrenze
- Verhindert das träge, unkorrigierte Umkippen des Roboters bei minimalen Winkelfehlern
  - Allerdings: Ruckartiges Anfahren und hohe Mindestdrehzahl
- Maßnahme 2: Dynamische Kickstart-Logik
- Beim Anfahren der Motoren
  - Bei abruptem Richtungswechsel oder aus dem Stillstand
- Für genau 7 Zyklen: mit voller Mindest-PWM angesteuert
  - Mechanisches Spiel im Getriebe wird instantan übersprungen und das Losbrechmoment sofort überwunden
- Danach: Ansteuerung mit niedrigerem PWM-Wert möglich (40 bis 50)
- Ermöglicht geringere Drehzahlen und feinfühligeres Einregeln der Ruhelage

M. Carrier J. Fritze – Selbstbalancierender Roboter

## Programmierung

- Motoransteuerung - Ergebnis
- Ergebnis: Verbesserung der Systemdynamik
- Haftreibung überwinden
- Realisierung geringerer Drehzahlen
- Sicherheitsabschaltung
- Bei Überschreiten eines Fehlers von 30° werden die Motoren abgeschaltet

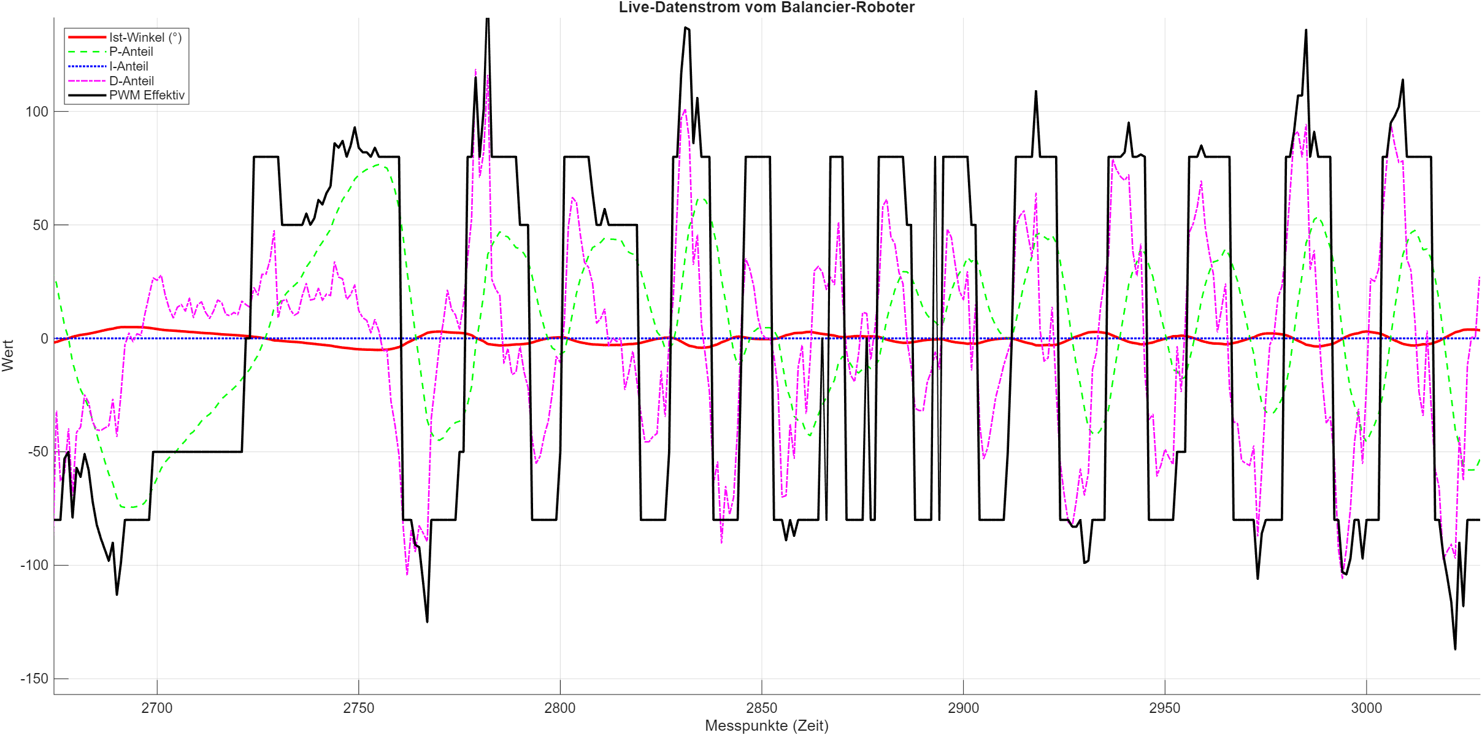
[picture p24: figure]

M. Carrier J. Fritze – Selbstbalancierender Roboter

## Programmierung

          - Live-Tuning
  - Der ESP32D stellt einen Webserver bereit, der über einen Browser aufgerufen werden kann
  - Für sparsamen Ressourcenumgang wird im Hauptloop nur überprüft ob eine Veränderung vorgenommen wurde
  - Vorteile:
      - Um den tatsächlichen Schwerpunkt zu finden wird das Live-Tuning benötigt
      - Ohne Live-Tuning wäre die richtige Kalibrierung schwerer umsetzbar
      - Ermöglicht eine schnellere Anpassung der Parameter, wodurch die Auswirkungen der Änderungen direkt sichtbarer werden
      - Zeitersparnis, da das Programm nach Parameteränderungen nicht erneut geflasht werden muss

M. Carrier J. Fritze – Selbstbalancierender Roboter

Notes: Wie ich am anfang erwähnt hatte nutzen wir die WLAN möglichkeit des ESP32D.
Der nutzen sieht wie folgt aus, das ESP32D erstellt einen Webserver, auf dem sich der User mit einem Notmalen Web browser einwählen kann
Hier können die daten dann live verändert werden, wo bei die Werte nicht jedesmal im loop durchgegangen werden, sondern im Hauptloop nur überprüft wird, ob werte verändert wurden
Vorteile:
Während die Kalibierung sehr nett ist, ist der Schwerpunkt des Roboters überhaupt nicht bei 0°
Was wir also machen, ist den Robtor in seinen Schwerpunkt bringen, der Schwerpunkt über die Anzeige Ablesen, und dann mit dem Angel offset den Sollwinkel anpassen
Dies wäre ohne Live Anpassung nicht machbar, weil jedesmal wenn wir flushen die Kalibierung ein bisschen anders ist und dementsprechend eine Kalibierung auf dem Laptop überhaupt nicht möglich wäre
Außerdem hat uns dies, bei der Parameterfindung geholfen, da wir die Parameter verändern konten und dann live mit verfolgen konnten, welchen einfluss dies auf das Verhalten des Roboters hatte
Auch abesehen von der verbesserten Wahrnebarkeit der Parameterveränderungen war es auch eine Große Zeitersparniss das ESP32D nicht für jeder änderung neu flushen zumüssen

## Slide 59

Ergebnisse

## Regelungstechnische Analyse mittels MATLAB

- Serielle Datenpipeline zur Regelanalyse aufgebaut
- Ausgabe der unskalierten PID-Anteile (P, I, D) und des Stellsignals u(t)
- Synchrone UART-Übertragung mit 200 Hz Schleifenfrequenz
- Grafische Auswertung der Systemantworten in MATLAB
- Unterstützung bei der Optimierung der Regelparameter
- Präzise Identifikation und Isolation komplexer Regelfehler
- Daten für spätere Analyse als CSV gespeichert

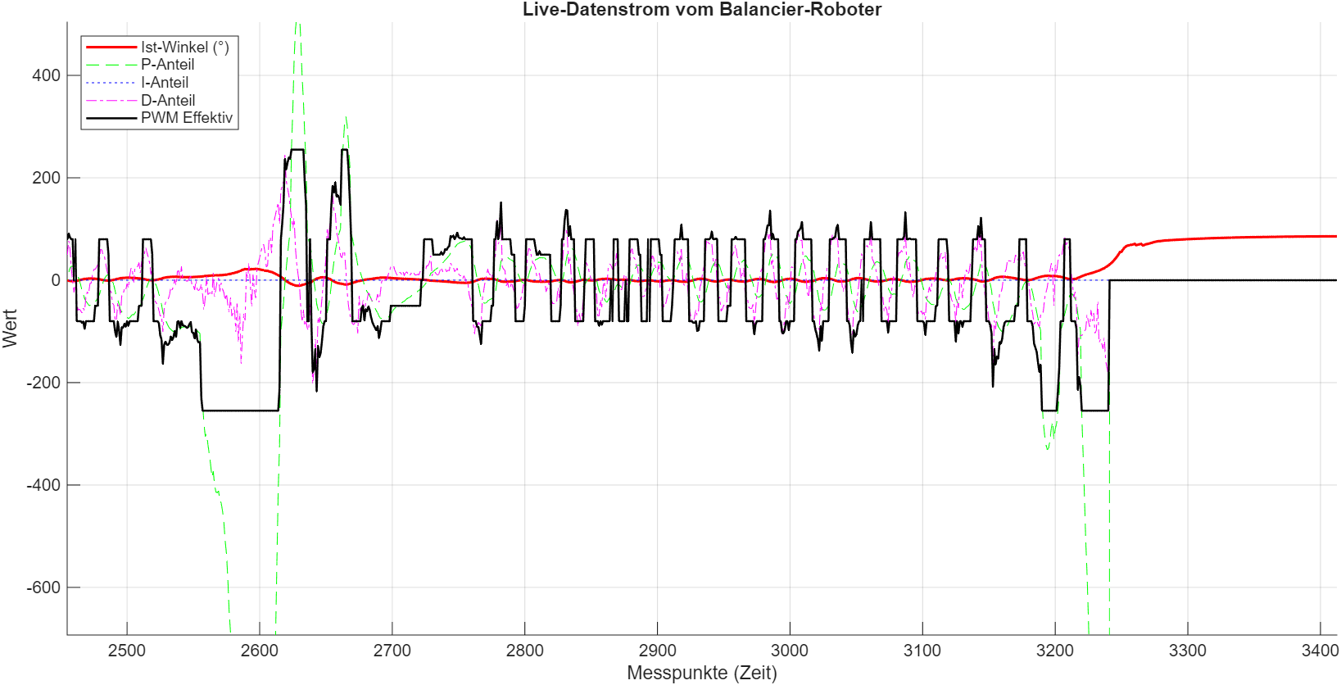
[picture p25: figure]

M. Carrier J. Fritze – Selbstbalancierender Roboter

## Ergebnisse und Systemverhalten

- Final verwendete Parameter
- Kp: 15.0
- Ki: 0.0
- Kd: 0.5
- Winkel-Offset: 0.0°
- Mindest-PWM: 80
- PWM-Frequenz: 200 Hz
- Es konnte keine dauerhafte Stabilisierung des Roboters erreicht werden
- Fehlerbild
  - Temporäre Stabilisierung um die Ruhelage
  - Kontinuierliches Aufschaukeln
  - Unkontrollierter Ausbruch zu einer Seite kann nicht mehr abgefangen werden

M. Carrier J. Fritze – Selbstbalancierender Roboter

## Ergebnisse und Systemverhalten

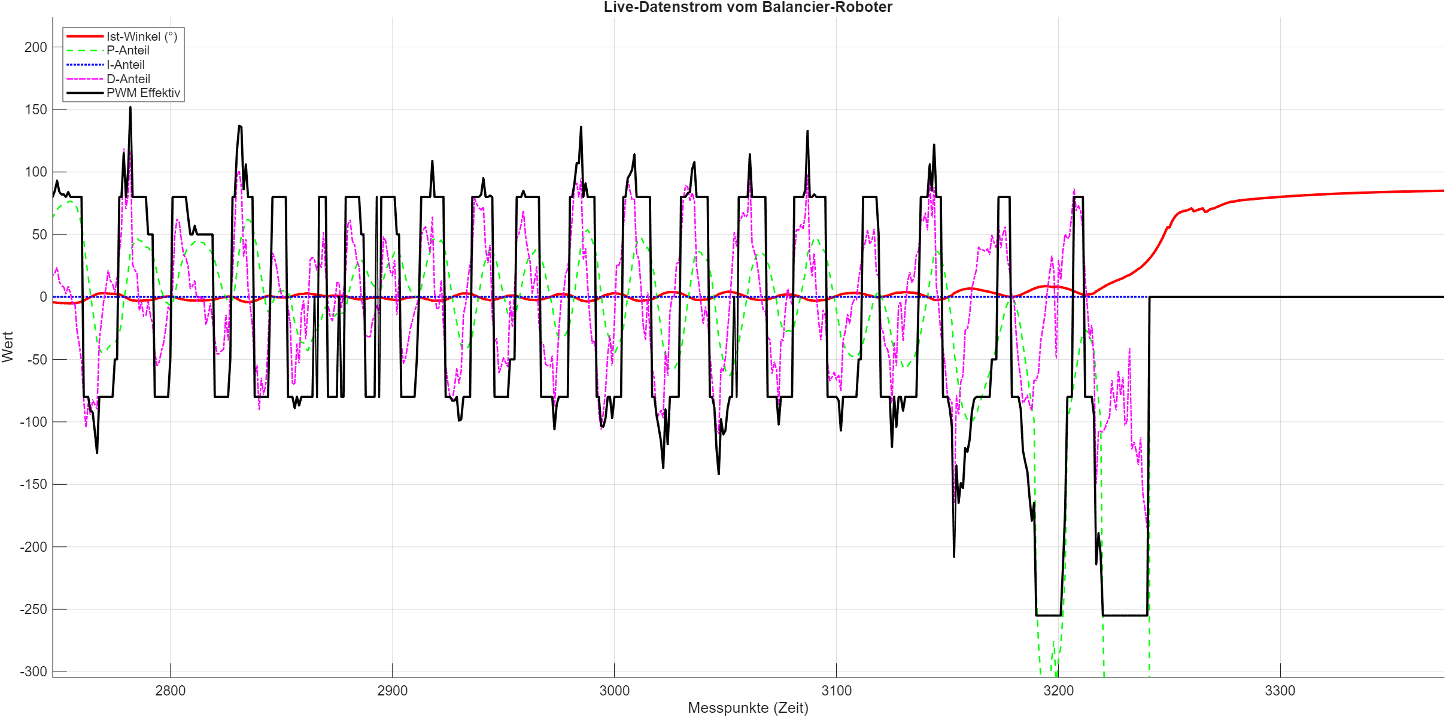
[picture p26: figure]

M. Carrier J. Fritze – Selbstbalancierender Roboter

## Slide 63

Ausblick

## Ausblick und Optimierungspotenziale

- Optimierung der Aktuatorik
- Reduzierung des Getriebespiels
- Dynamisches Anlaufverhalten
- Drehzahlreserven
- Mechanisches Design und Massenverteilung
- Erhöhung des Massenträgheitsmoments
- Geometrische Anpassung
- Fazit
- Interessantes Projekt, um theoretisches Wissen auf die Praxis zu übertragen
- Theorie der Regelungstechnik scheitert an Unwägbarkeiten des mechanischen Systems

M. Carrier J. Fritze – Selbstbalancierender Roboter

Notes: Reduzierung des Getriebespiels:
Hohes Spiel
Kleine Regelseganle werden dadurch nicht auf die Räderübertragen
Planetenrad getriebe oder Schrittmotoren wären besser
Dynamisches Anlaufverhalten:
Die nächsten beiden punkte sind symptom der selben Ursache, die Motoren sind nicht schnell genug.
Sie brauchen eine Hohe PWM circa. 100 um eine erste reaction zu zeigen und danach fehlt spielraum
Das ist auf der einen Seite bessere Motoren und auf der anderen Seite ein geringeres übersetzungsverhältniss
Erhöhung des Massenträgheitsmoments
Invertiertes pendel, lässt sich Leichter regeln um so langsamer es fällt.
Schwere Komponenten nach oben
Geometrische Anpassung
Größere Räder

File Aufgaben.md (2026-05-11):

Aufgaben:
    Maße der Bauteile überprüfen

    Grundkörper konstruieren
        Entwicklungsboard nachbauen
        Dämpfer integrieren, kein Schaden beim umkippen

    Dokumentation erstellen - LaTeX?
        Welche Ziele haben wir
            Schritt 1 - reine Balance
            Schritt 2 - Kommunikation mit Smartphone
                über BLE 
                Winkel und Richtung vorgeben
            Schritt 3 - Kurvenfahrten, Rückwärtsfahrten und veränderbare Geschwindigkeit implementieren
                Ausgang aus dem Regelkreis entsprechend auf die Räder aufteilen
    
    Aufgabenteilung überlegen

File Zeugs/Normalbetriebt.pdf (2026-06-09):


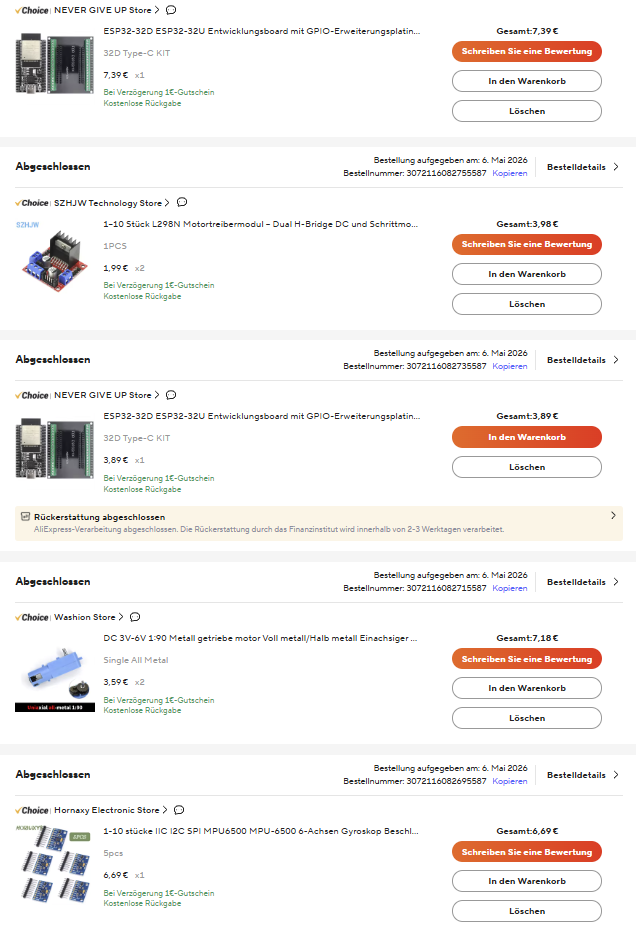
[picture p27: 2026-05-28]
Screenshot 2026-05-28 150755.png

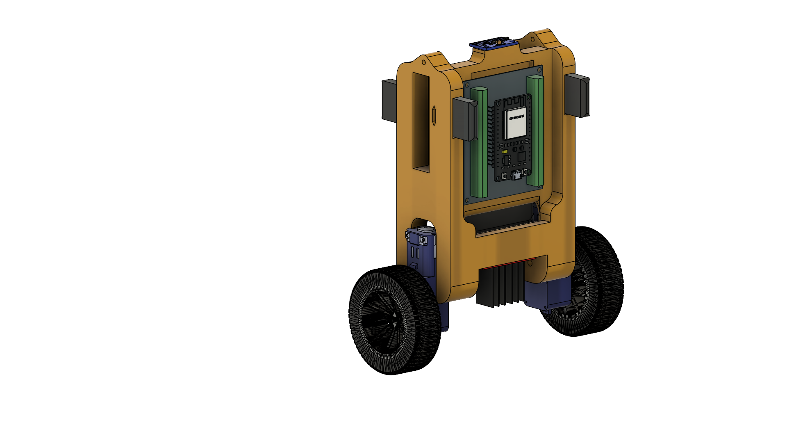
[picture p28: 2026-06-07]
Bilder/Gesamtsystem_vorn.png

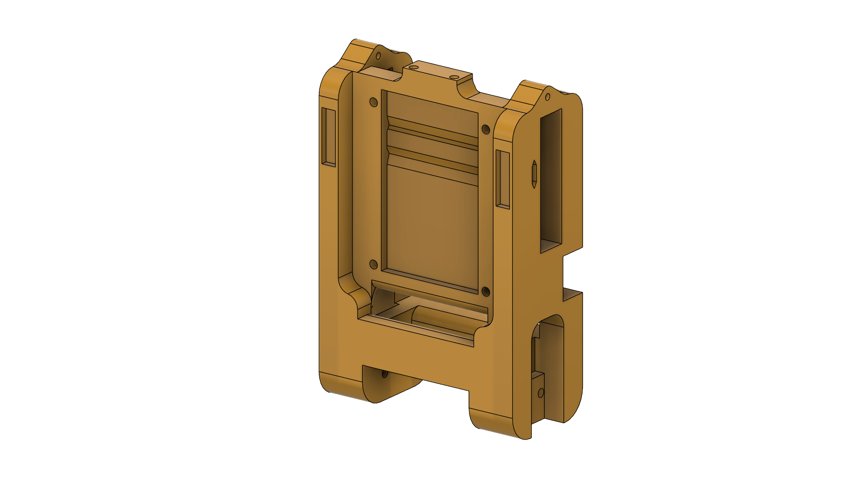
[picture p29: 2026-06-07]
Bilder/Grundkörper.png

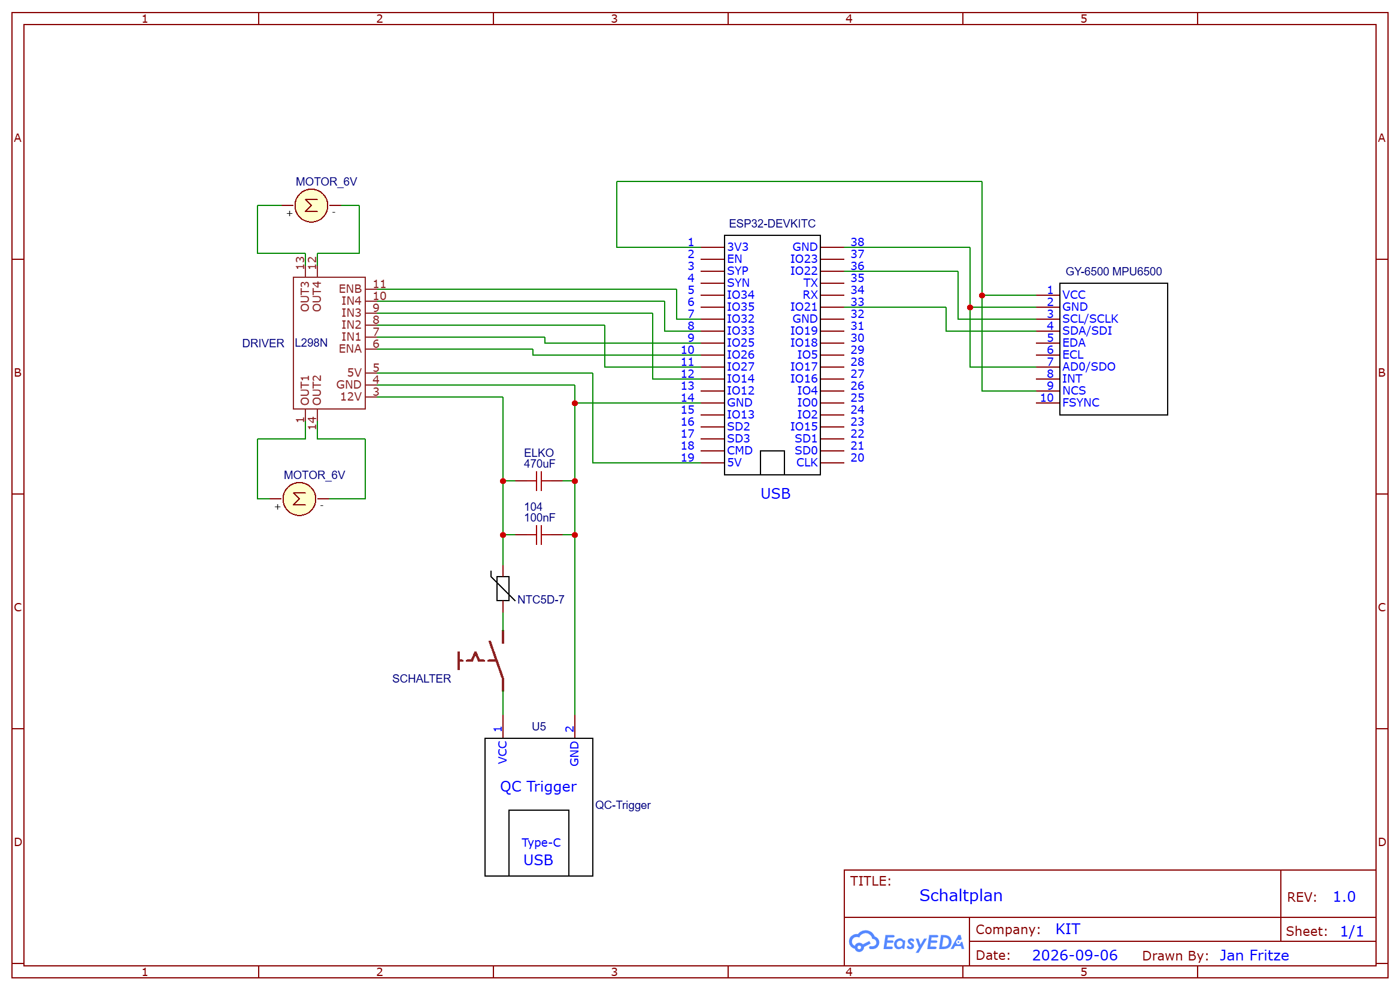
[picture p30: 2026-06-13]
Schaltkreise/Schaltplan_final.png

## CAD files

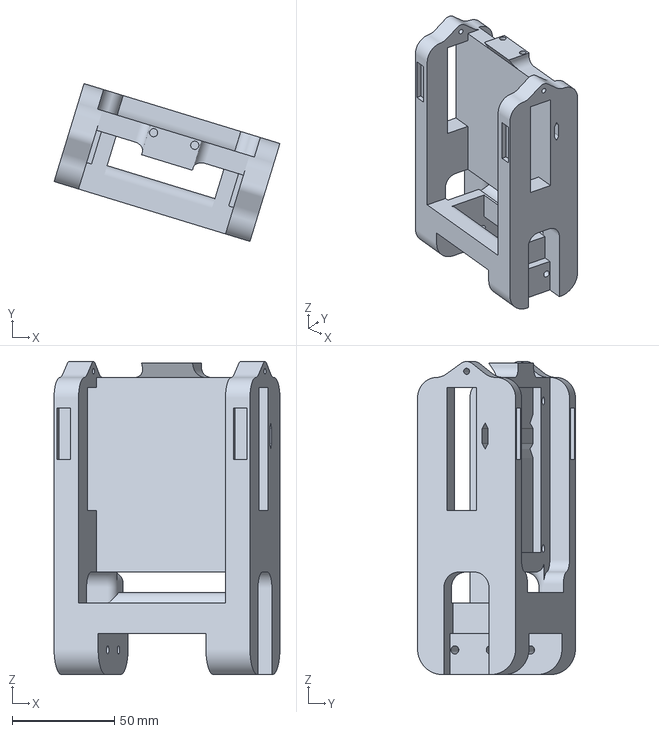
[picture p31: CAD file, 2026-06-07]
Grundkörper.3mf
110.2 x 77.1 x 152.8 mm

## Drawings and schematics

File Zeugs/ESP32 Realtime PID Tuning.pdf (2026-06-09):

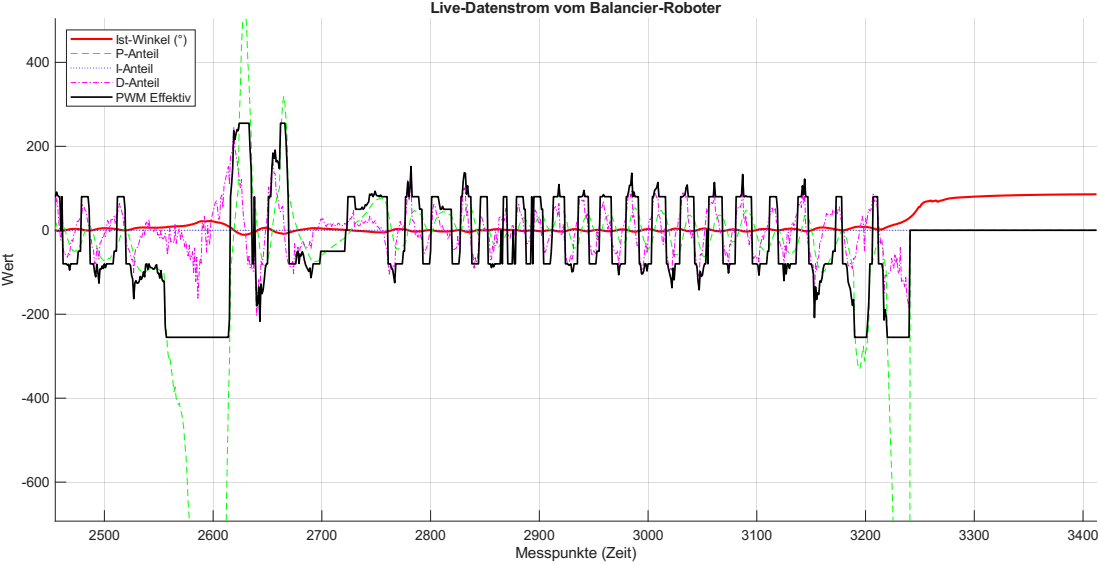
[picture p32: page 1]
Messpunkte (Zeit); ert; Ist-Winkel (°) P-Anteil I-Anteil D-Anteil PWM Effektiv

Live-Datenstrom vom Balancier-Roboter

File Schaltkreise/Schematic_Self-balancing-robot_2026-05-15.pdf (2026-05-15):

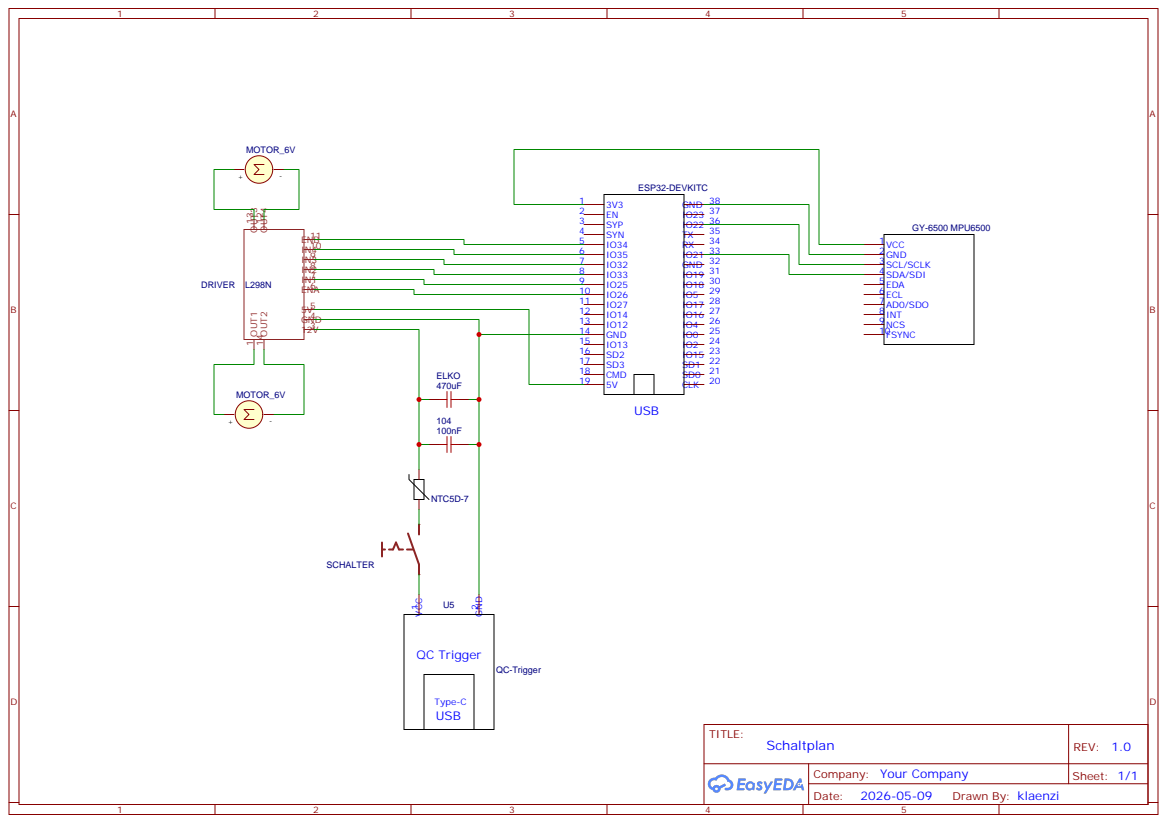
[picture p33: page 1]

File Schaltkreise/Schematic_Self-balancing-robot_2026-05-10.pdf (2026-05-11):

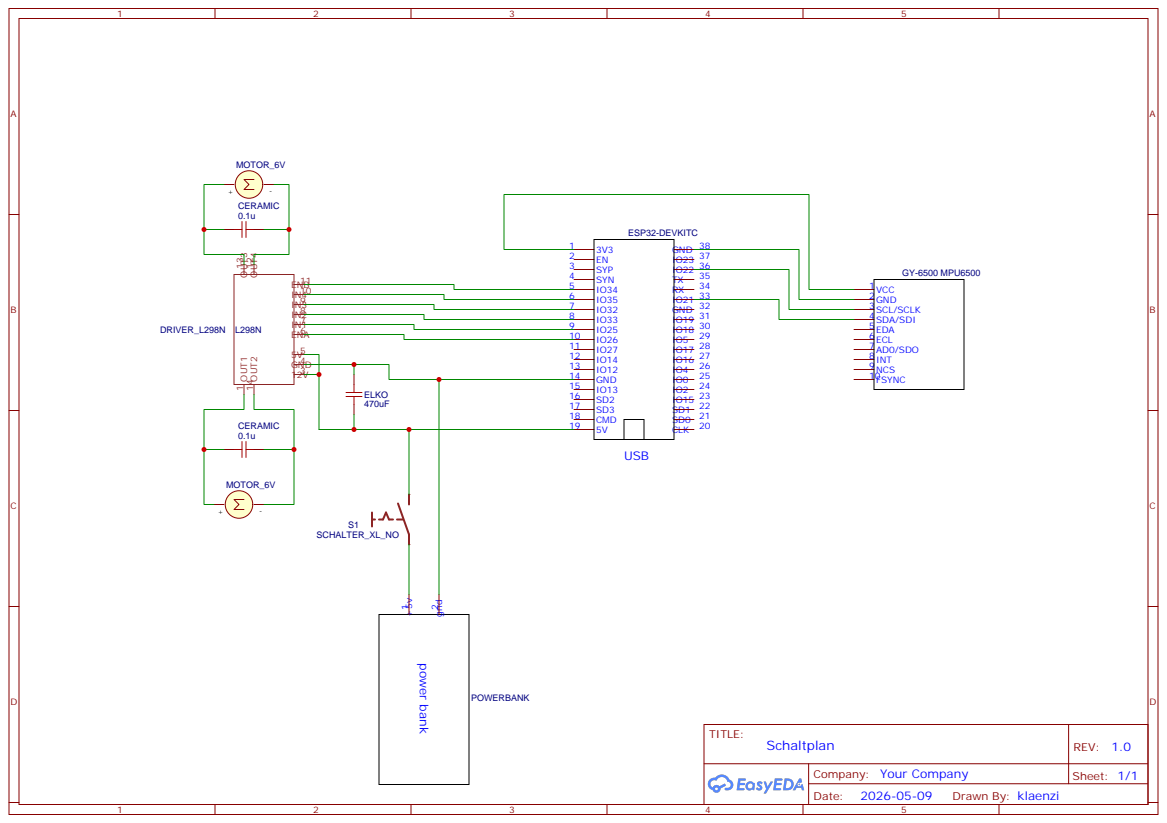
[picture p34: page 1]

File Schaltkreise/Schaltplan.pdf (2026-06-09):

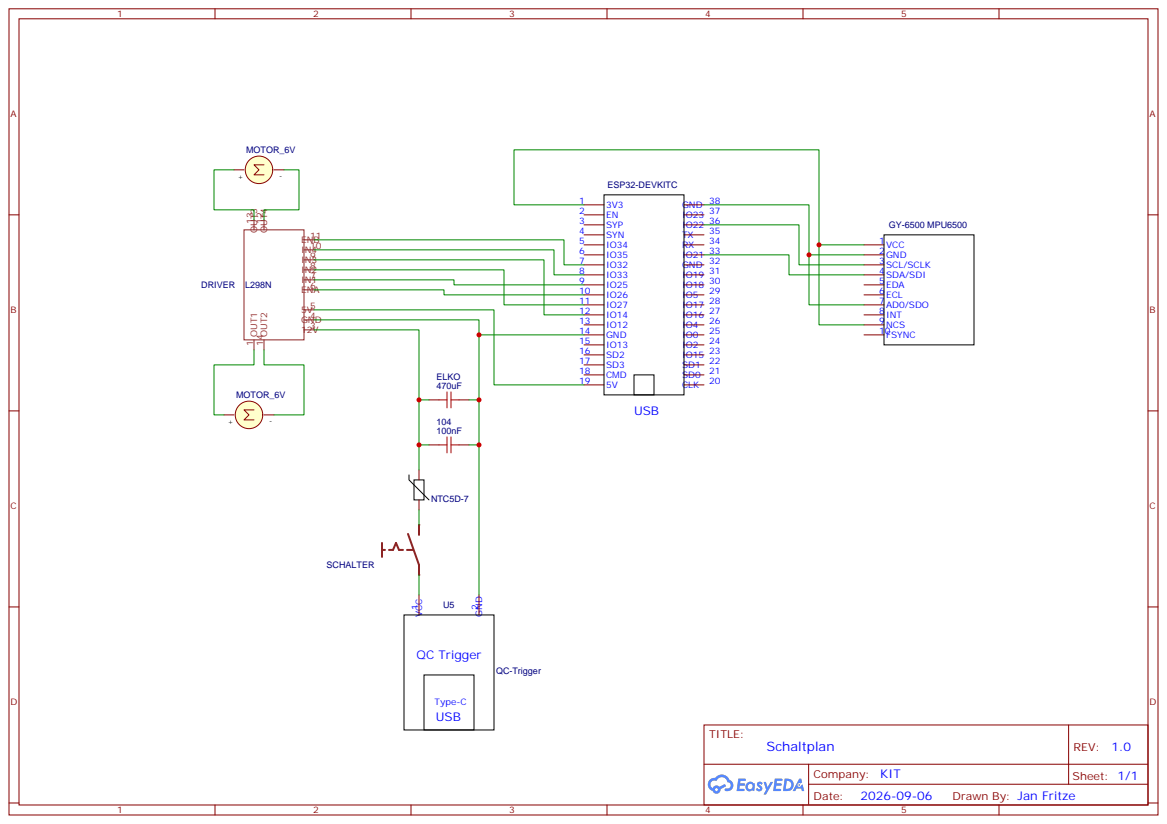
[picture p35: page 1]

Drawn By: Jan Fritze

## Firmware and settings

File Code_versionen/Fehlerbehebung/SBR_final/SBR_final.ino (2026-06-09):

/*
  Self-Balancing Robot - ESP32

  -------------------------------------------------------
  MPU6500 Wiring
  -------------------------------------------------------
  VCC  -> 3V3
  GND  -> GND
  SDA  -> GPIO23
  SCL  -> GPIO18
  NCS  -> 3V3   (aktiviert I2C Modus!)
  AD0  -> GND   (I2C Adresse 0x68)

  -------------------------------------------------------
  L298N Wiring
  -------------------------------------------------------
  ENA  -> GPIO26
  IN1  -> GPIO25
  IN2  -> GPIO27
  IN3  -> GPIO14
  IN4  -> GPIO33
  ENB  -> GPIO32
*/

#include <Wire.h>
#include <WiFi.h>
#include <WebServer.h>

// =======================================================
// Webserver Konfiguration
// =======================================================
const char* ssid = "BalancingRobot_Tuning";
const char* password = "12345678"; // Mindestens 8 Zeichen
WebServer server(80);

// =======================================================
// Motor Pins
// =======================================================

const int ENA = 26;
const int IN1 = 25;
const int IN2 = 27;

const int IN3 = 14;
const int IN4 = 33;
const int ENB = 32;

// --- PROFIL 1: Niedrige Frequenz (Hohes Drehmoment) ---
int PWM_FREQ             = 200;     // über Webserver einstellbar
const int PWM_RESOLUTION = 8;       // 0-255
const int MAX_PWM        = 255;
int MIN_START_PWM        = 80;      // über Webserver einstellbar
const int MIN_HOLD_PWM   = 50;     

// Motor-Trimm-Faktor
const float TRIM_LEFT  = 1.00f;     // ungenutzt
const float TRIM_RIGHT = 1.00f;     // ungenutzt

// =======================================================
// KICKSTART & RICHTUNGSWECHSEL LOGIK
// =======================================================
const int KICKSTART_CYCLES = 7;    

int kickCounterLeft = 0;
int kickCounterRight = 0;

int lastSignLeft = 0; 
int lastSignRight = 0;

int actualPwmLeft = 0;      // für die Ausgabe im Monitor
int actualPwmRight = 0;     // für die Ausgabe im Monitor

// =======================================================
// MPU6500 Parameters
// =======================================================

#define MPU_ADDR  0x68
#define LOOP_HZ   200
#define LOOP_US   (1000000 / LOOP_HZ)  // 5000 us

const float COMPLEMENTARY_ALPHA = 0.98f;
const float GYRO_LP_ALPHA       = 0.8f;
const float ACCEL_MAG_HIGH      = 13.0f;
const float ACCEL_MAG_LOW       =  9.0f;
const int   CALIB_SAMPLES       = 500;

float pitchDeg         = 0.0f;      // aktueller pitch
float gyroOffsetY      = 0.0f;      // mathematischer Fehler des Gyroskops (Sensor-Drift)
float gyroRateFiltered = 0.0f;      // gefilterte Winkelgeschwindigkeit

// Mechanischer Offset, um den physikalischen Schwerpunkt zu trimmen
float angleOffset      = 0.0f;     // über Webserver einstellbar --> ändert sich bei jedem Einschalten minimal

// =======================================================
// PID Tunings & Globale Plot-Variablen
// =======================================================

float Kp = 15.0f;       // über Webserver einstellbar
float Ki = 0.0f;        // über Webserver einstellbar
float Kd = 0.5f;        // über Webserver einstellbar

float setpointDeg   = 0.0f;       // Sollwinkel
float integral      = 0.0f;
float previousError = 0.0f;

const float INTEGRAL_LIMIT   = 300.0f;
const float FALL_ANGLE_LIMIT = 30.0f;     // ab diesem Winkel werden die Motoren abgestellt

// Globale Variablen, damit der serielle Plotter die Einzelanteile mitschreiben kann
float last_P_out = 0.0f;
float last_I_out = 0.0f;
float last_D_out = 0.0f;

// =======================================================
// Timing
// =======================================================

unsigned long lastLoopMicros   = 0;
unsigned long lastSerialMillis = 0;

// =======================================================
// HTML Dashboard Template
// =======================================================

void handleRoot() {
  String html = "<!DOCTYPE html><html><head><meta charset='UTF-8'>";
  html += "<meta name='viewport' content='width=device-width, initial-scale=1.0'>";
  html += "<title>Robot PID Tuning</title>";
  html += "<style>body{font-family:Arial,sans-serif;background:#f4f4f9;padding:20px;color:#333;}";
  html += ".card{background:white;padding:20px;border-radius:10px;box-shadow:0 4px 8px rgba(0,0,0,0.1);max-width:400px;margin:0 auto;}";
  html += "h2{text-align:center;color:#007BFF;} .form-group{margin-bottom:15px;}";
  html += "label{display:block;margin-bottom:5px;font-weight:bold;}";
  html += "input[type='number']{width:100%;padding:8px;box-sizing:border-box;border:1px solid #ccc;border-radius:5px;}";
  html += "button{width:100%;padding:10px;background:#007BFF;border:none;color:white;font-size:16px;border-radius:5px;cursor:pointer;margin-top:10px;}";
  html += "button:hover{background:#0056b3;}";
  html += ".angle-box{text-align:center;font-size:24px;font-weight:bold;margin:15px 0;padding:10px;background:#e9ecef;border-radius:5px;color:#495057;}</style>";
  
  // JavaScript für das automatische Live-Update des Winkels im Webserver (AJAX)
  html += "<script>setInterval(function(){";
  html += "  var xhttp = new XMLHttpRequest();";
  html += "  xhttp.onreadystatechange = function() {";
  html += "    if (this.readyState == 4 && this.status == 200) {";
  html += "      document.getElementById('live_angle').innerHTML = this.responseText + ' °';";
  // Dynamische Farbe: Rot bei Sturz/großem Fehler, Grün bei Balance
  html += "      var angle = Math.abs(parseFloat(this.responseText));";
  html += "      if(angle > 5.0){ document.getElementById('live_angle').style.color = '#dc3545'; }";
  html += "      else { document.getElementById('live_angle').style.color = '#28a745'; }";
  html += "    }";
  html += "  };";
  html += "  xhttp.open('GET', '/getAngle', true);";
  html += "  xhttp.send();";
  html += "}, 50);</script>"; // Aktualisiert alle 200ms im Browser
  
  html += "</head><body>";
  
  html += "<div class='card'><h2>PID & Motor Live Tuning</h2>";
  
  // Live Winkel Anzeige Box
  html += "<label style='text-align:center;'>Aktueller Winkel:</label>";
  html += "<div class='angle-box' id='live_angle'>0.00 °</div>";
  
  html += "<form action='/save' method='POST'>";
  html += "<div class='form-group'><label>Kp:</label><input type='number' step='0.1' name='kp' value='" + String(Kp) + "'></div>";
  html += "<div class='form-group'><label>Ki:</label><input type='number' step='0.01' name='ki' value='" + String(Ki) + "'></div>";
  html += "<div class='form-group'><label>Kd:</label><input type='number' step='0.01' name='kd' value='" + String(Kd) + "'></div>";
  html += "<div class='form-group'><label>Angle Offset (°):</label><input type='number' step='0.1' name='offset' value='" + String(angleOffset) + "'></div>";
  html += "<div class='form-group'><label>MIN START PWM:</label><input type='number' step='1' name='min_start' value='" + String(MIN_START_PWM) + "'></div>";
  html += "<div class='form-group'><label>PWM Frequenz (Hz):</label><input type='number' step='1' name='freq' value='" + String(PWM_FREQ) + "'></div>";
  
  html += "<button type='submit'>Speichern & Übernehmen</button>";
  html += "</form></div></body></html>";
  
  server.send(200, "text/html", html);
}

void handleSave() {
  if (server.hasArg("kp")) Kp = server.arg("kp").toFloat();
  if (server.hasArg("ki")) Ki = server.arg("ki").toFloat();
  if (server.hasArg("kd")) Kd = server.arg("kd").toFloat();
  if (server.hasArg("offset")) angleOffset = server.arg("offset").toFloat();
  if (server.hasArg("min_start")) MIN_START_PWM = server.arg("min_start").toInt();
  
  if (server.hasArg("freq")) {
    int newFreq = server.arg("freq").toInt();
    if (newFreq != PWM_FREQ) {
      PWM_FREQ = newFreq;
      ledcAttach(ENA, PWM_FREQ, PWM_RESOLUTION);
      ledcAttach(ENB, PWM_FREQ, PWM_RESOLUTION);
    }
  }
  
  server.sendHeader("Location", "/");
  server.send(333, "text/plain", "Bereit");
}

// Endpoint für das JavaScript, um den Winkel abzufragen
void handleGetAngle() {
  server.send(200, "text/plain", String(pitchDeg, 2));
}

// =======================================================
// Motor Funktionen
// =======================================================

void setMotor(int ena, int in1, int in2, int command, int &kickCounter, int &lastSign, int &actualPwmStore) {
  command = constrain(command, -255, 255);
  int pwm = abs(command);

  int currentSign = (command > 0) ? 1 : ((command < 0) ? -1 : 0);

  if (pwm == 0) {
    digitalWrite(in1, LOW);
    digitalWrite(in2, LOW);
    ledcWrite(ena, 0);
    kickCounter = 0; 
    lastSign = 0;
    actualPwmStore = 0;
    return;
  }

  if (currentSign != lastSign && lastSign != 0) {
    kickCounter = 0; 
  }
  lastSign = currentSign; 

  if (pwm < MIN_START_PWM) {
    if (kickCounter < KICKSTART_CYCLES) {
      pwm = MIN_START_PWM; 
      kickCounter++; 
    } else {
      if (pwm < MIN_HOLD_PWM) {
        pwm = MIN_HOLD_PWM;
      }
    }
  } else {
    kickCounter = 0; 
  }

  pwm = constrain(pwm, 0, MAX_PWM);
  actualPwmStore = pwm;

  if (command > 0) {
    digitalWrite(in1, HIGH);
    digitalWrite(in2, LOW);
  } else if (command < 0) {
    digitalWrite(in1, LOW);
    digitalWrite(in2, HIGH);
  }

  ledcWrite(ena, pwm);
}

void setMotors(int command) {
  int commandLeft  = (int)(command * TRIM_LEFT);
  int commandRight = (int)(command * TRIM_RIGHT);

  setMotor(ENA, IN1, IN2, commandLeft, kickCounterLeft, lastSignLeft, actualPwmLeft);
  setMotor(ENB, IN3, IN4, commandRight, kickCounterRight, lastSignRight, actualPwmRight);
}

void stopMotors() {
  setMotors(0);
}

// =======================================================
// I2C Hilfsfunktionen
// =======================================================

void writeMPU(byte reg, byte val) {
  Wire.beginTransmission(MPU_ADDR);
  Wire.write(reg);
  Wire.write(val);
  Wire.endTransmission();
}

void readAll(float &ax, float &ay, float &az,
             float &gx, float &gy, float &gz) {

  Wire.beginTransmission(MPU_ADDR);
  Wire.write(0x3B);
  Wire.endTransmission(false);
  Wire.requestFrom(MPU_ADDR, 14);

  int16_t rawAx = (Wire.read() << 8) | Wire.read();
  int16_t rawAy = (Wire.read() << 8) | Wire.read();
  int16_t rawAz = (Wire.read() << 8) | Wire.read();
  Wire.read(); Wire.read();
  int16_t rawGx = (Wire.read() << 8) | Wire.read();
  int16_t rawGy = (Wire.read() << 8) | Wire.read();
  int16_t rawGz = (Wire.read() << 8) | Wire.read();

  ax = (rawAx / 16384.0f) * 9.81f;
  ay = (rawAy / 16384.0f) * 9.81f;
  az = (rawAz / 16384.0f) * 9.81f;

  gx = rawGx / 65.5f;
  gy = rawGy / 65.5f;
  gz = rawGz / 65.5f;
}

// =======================================================
// Kalibrierung
// =======================================================

void calibrateGyro() {
  Serial.println("Kalibriere Gyro - Roboter stillhalten...");
  float sumY = 0.0f;

  for (int i = 0; i < CALIB_SAMPLES; i++) {
    float ax, ay, az, gx, gy, gz;
    readAll(ax, ay, az, gx, gy, gz);
    sumY += gy;
    delay(2);
  }

  gyroOffsetY = sumY / CALIB_SAMPLES;
  Serial.print("Gyro Offset Y: ");
  Serial.println(gyroOffsetY, 4);
  Serial.println("Kalibrierung fertig.");
}

// =======================================================
// Pitch berechnen
// =======================================================

void updatePitch(float dt,
                 float ax, float ay, float az,
                 float gy) {

  float accelPitch = atan2(-ax, az) * 180.0f / PI;
  float gyroRate   = gy - gyroOffsetY;

  if (isnan(accelPitch) || isnan(gyroRate)) return;

  gyroRate = constrain(gyroRate, -500.0f, 500.0f);

  gyroRateFiltered = GYRO_LP_ALPHA * gyroRateFiltered
                    + (1.0f - GYRO_LP_ALPHA) * gyroRate;

  float accelMag = sqrt(ax*ax + ay*ay + az*az);
  float alpha    = (accelMag > ACCEL_MAG_HIGH ||
                    accelMag < ACCEL_MAG_LOW) ? 1.0f : COMPLEMENTARY_ALPHA;

  float rawPitch = alpha * (pitchDeg + angleOffset + gyroRateFiltered * dt)
                   + (1.0f - alpha) * accelPitch;

  pitchDeg = rawPitch - angleOffset;
  pitchDeg = constrain(pitchDeg, -90.0f, 90.0f);
}

// =======================================================
// PID (Mit Einzelwert-Speicherung für den Plotter)
// =======================================================

float computePID(float dt) {
  float error = setpointDeg - pitchDeg;

  // --- ANTI-WIND-UP-SCHUTZ ---
  if (abs(error) < 3.0f) {
    integral += error * dt;
    integral  = constrain(integral, -INTEGRAL_LIMIT, INTEGRAL_LIMIT);
  } else {
    integral = 0.0f; 
  }

  const float FIXED_DT = 0.005f;
  float derivative  = (error - previousError) / FIXED_DT;
  previousError     = error;

  // P-Anteil mit progressiver Kennlinie berechnen
  float P = Kp * error;
  if (abs(error) > 7.0f) {
    P = Kp * (error * abs(error) * 0.3f); 
  }

  float I = Ki * integral;
  float D = Kd * derivative;

  // Werte für die serielle Ausgabe sichern
  last_P_out = P;
  last_I_out = I;
  last_D_out = D;

  float output = P + I + D;
  return constrain(output, -255.0f, 255.0f);
}

// =======================================================
// Setup
// =======================================================

void setup() {
  Serial.begin(115200);
  delay(500);
  Serial.println("ESP32 startet im Balance-Modus...");

  // Motor Pins
  pinMode(IN1, OUTPUT); pinMode(IN2, OUTPUT);
  pinMode(IN3, OUTPUT); pinMode(IN4, OUTPUT);

  ledcAttach(ENA, PWM_FREQ, PWM_RESOLUTION);
  ledcAttach(ENB, PWM_FREQ, PWM_RESOLUTION);

  stopMotors();

  // I2C
  Wire.begin(23, 18);
  Wire.setClock(400000);
  delay(100);

  // MPU6500 initialisieren
  writeMPU(0x6B, 0x80);   // Reset
  delay(100);
  writeMPU(0x6B, 0x01);   // Wake up
  delay(100);
  writeMPU(0x68, 0x07);   // Signal Path Reset
  delay(100);
  writeMPU(0x1B, 0x08);   // Gyro:  +-500 deg/s
  writeMPU(0x1C, 0x00);   // Accel: +-2g
  writeMPU(0x1A, 0x01);   // DLPF:  184 Hz

  calibrateGyro();

  // Startwinkel bestimmen
  float ax, ay, az, gx, gy, gz;
  readAll(ax, ay, az, gx, gy, gz);
  pitchDeg = atan2(-ax, az) * 180.0f / PI;

  // Access Point aufmachen
  WiFi.softAP(ssid, password);
  Serial.println("WLAN Access Point gestartet!");
  Serial.print("IP-Adresse: ");
  Serial.println(WiFi.softAPIP());

  // Webserver URLs verknüpfen (start() durch korrekte Funktion begin() ersetzt)
  server.on("/", handleRoot);
  server.on("/save", HTTP_POST, handleSave);
  server.on("/getAngle", HTTP_GET, handleGetAngle); // Neuer Live-Winkel-Endpoint
  server.begin();
  Serial.println("Webserver gestartet.");

  Serial.println("SYSTEM READY - Balancierung aktiv.");
  lastLoopMicros = micros();
}

// =======================================================
// Loop
// =======================================================

void loop() {
  server.handleClient();

  unsigned long now = micros();
  if (now - lastLoopMicros < LOOP_US) return;

  float dt = (now - lastLoopMicros) / 1000000.0f;
  lastLoopMicros = now;

  if (dt > 0.05f) {
    float ax, ay, az, gx, gy, gz;
    readAll(ax, ay, az, gx, gy, gz);
    pitchDeg      = atan2(-ax, az) * 180.0f / PI;
    integral      = 0.0f;
    previousError = 0.0f;
    stopMotors();
    return;
  }

  float ax, ay, az, gx, gy, gz;
  readAll(ax, ay, az, gx, gy, gz);

  updatePitch(dt, ax, ay, az, gy);

  int motorCommand = 0; // Hier wird sie das erste und einzige Mal deklariert!

  if (abs(pitchDeg) > FALL_ANGLE_LIMIT) {
    stopMotors();
    integral      = 0.0f;
    previousError = 0.0f;
    // Auch die Plot-Werte im Sturz nullen
    last_P_out = 0.0f; last_I_out = 0.0f; last_D_out = 0.0f;
  } else {
    motorCommand = (int)computePID(dt);
    setMotors(motorCommand);
  }

  // Datenausgabe für den IDE Seriellen Plotter / MATLAB mit vollen 200 Hz
  lastSerialMillis = millis();
  
  // 1. Winkeldaten
  Serial.print("Ist-Pitch:"); Serial.print(pitchDeg, 2);
  Serial.print(" ");
  
  // 2. Die einzelnen PID-Kanal-Anteile unskaliert (direkter PWM-Einfluss von -255 bis 255)
  Serial.print("P-Anteil:"); Serial.print(last_P_out, 1);
  Serial.print(" ");
  Serial.print("I-Anteil:"); Serial.print(last_I_out, 1);
  Serial.print(" ");
  Serial.print("D-Anteil:"); Serial.print(last_D_out, 1);
  Serial.print(" ");

  // 3. Reales Gesamtsignal am Motor
  int realPwmAverage = (actualPwmLeft + actualPwmRight) / 2;
  // Wir nutzen hier direkt das oben berechnete motorCommand für das Vorzeichen (OHNE neues 'int'!)
  int signedRealPwm = (motorCommand >= 0) ? realPwmAverage : -realPwmAverage;
  Serial.print("PWM_Effektiv:"); Serial.print(signedRealPwm);
  
  Serial.println(); 
}

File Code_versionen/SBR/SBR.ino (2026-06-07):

/*
  Self-Balancing Robot - ESP32
  MPU6500 (I2C) + Webserver + PID + L298N

  -------------------------------------------------------
  MPU6500 Wiring
  -------------------------------------------------------
  VCC  -> 3V3
  GND  -> GND
  SDA  -> GPIO23
  SCL  -> GPIO18
  NCS  -> 3V3   (aktiviert I2C Modus!)
  AD0  -> GND   (I2C Adresse 0x68)

  -------------------------------------------------------
  L298N Wiring
  -------------------------------------------------------
  ENA  -> GPIO26
  IN1  -> GPIO25
  IN2  -> GPIO27
  IN3  -> GPIO14
  IN4  -> GPIO33
  ENB  -> GPIO32

  -------------------------------------------------------
  Webserver
  -------------------------------------------------------
  1. Mit dem Netzwerk "ESP32-Control" verbinden (Passwort: 12345678)
  2. Browser: http://192.168.4.1
*/

#include <WiFi.h>
#include <WebServer.h>
#include <ArduinoJson.h>
#include <Wire.h>

// =======================================================
// WiFi
// =======================================================

const char* ssid     = "ESP32-Control";
const char* password = "12345678";

WebServer server(80);

// =======================================================
// Motor Pins
// =======================================================

const int ENA = 26;
const int IN1 = 25;
const int IN2 = 27;

const int IN3 = 14;
const int IN4 = 33;
const int ENB = 32;

const int PWM_FREQ       = 1000;    // Niedrige Frequenz für besseres Drehmoment am L298N
const int PWM_RESOLUTION = 8;       // 0-255
const int MAX_PWM        = 255;
const int MIN_START_PWM  = 100;      // Mindestwert damit Motoren anlaufen

// Motor-Trimm-Faktor
const float TRIM_LEFT  = 1.00f;  // 100% Leistung
const float TRIM_RIGHT = 1.00f;  // 100% Leistung

// =======================================================
// MPU6500
// =======================================================

#define MPU_ADDR  0x68
#define LOOP_HZ   200
#define LOOP_US   (1000000 / LOOP_HZ)  // 5000 us

const float COMPLEMENTARY_ALPHA = 0.98f;
const float GYRO_LP_ALPHA       = 0.8f;
const float ACCEL_MAG_HIGH      = 13.0f;
const float ACCEL_MAG_LOW       =  9.0f;
const int   CALIB_SAMPLES       = 500;

float pitchDeg         = 0.0f;
float gyroOffsetY      = 0.0f;
float gyroRateFiltered = 0.0f;

// Mechanischer Offset, um den physikalischen Schwerpunkt zu trimmen
float angleOffset      = -2.8f; 

// =======================================================
// PID
// =======================================================

float Kp = 20.0f;
float Ki = 50.0f;
float Kd = 0.5f;

float setpointDeg   = 0.0f;
float integral      = 0.0f;
float previousError = 0.0f;

const float INTEGRAL_LIMIT   = 300.0f;
const float FALL_ANGLE_LIMIT = 35.0f;

// =======================================================
// Joystick
// =======================================================

float joystickX = 0.0f;
float joystickY = 0.0f;

const float JOYSTICK_ANGLE_TRIM_MAX = 4.0f;

// =======================================================
// Timing
// =======================================================

unsigned long lastLoopMicros   = 0;
unsigned long lastSerialMillis = 0;

// =======================================================
// Website (Aktualisiert mit Offset-Buttons)
// =======================================================

const char MAIN_page[] PROGMEM = R"=====(
<!DOCTYPE html>
<html>
<head>
  <meta name="viewport" content="width=device-width, initial-scale=1">
  <title>Robot Controller</title>
  <style>
    body {
      background: #202020;
      color: white;
      text-align: center;
      font-family: Arial;
      user-select: none;
    }
    canvas {
      display: block;
      margin: 20px auto;
      touch-action: none;
    }
    input {
      font-size: 20px;
      width: 120px;
      padding: 8px;
      margin: 5px;
    }
    label {
      font-size: 20px;
    }
    .pid-row, .offset-row {
      display: flex;
      justify-content: center;
      gap: 20px;
      flex-wrap: wrap;
      margin: 10px 0;
    }
    .pid-field {
      display: flex;
      flex-direction: column;
      align-items: center;
    }
    button {
      font-size: 20px;
      padding: 10px 30px;
      margin: 10px;
      background: #505050;
      color: white;
      border: none;
      border-radius: 8px;
      cursor: pointer;
    }
    button:active {
      background: #707070;
    }
    .btn-offset {
      font-size: 24px;
      padding: 15px 25px;
      background: #2c5282;
    }
    .btn-offset:active {
      background: #4299e1;
    }
    #status     { font-size: 16px; color: #aaa; margin-top: 8px; }
    #pid-status { font-size: 16px; color: #aaa; margin-top: 8px; }
    #offset-val { font-size: 24px; font-weight: bold; color: #63b3ed; margin: 10px 0; }
  </style>
</head>
<body>

  <h1>ESP32 Robot Controller</h1>

  <h2>Joystick</h2>
  <canvas id="joystick" width="250" height="250"></canvas>
  <p id="status"></p>

  <h2>Balance Nullpunkt-Trimmung</h2>
  <div id="offset-val">0.0°</div>
  <div class="offset-row">
    <button class="btn-offset" onclick="adjustOffset(-0.1)">- 0.1°</button>
    <button class="btn-offset" onclick="adjustOffset(0.1)">+ 0.1°</button>
  </div>

  <h2>PID-Parameter</h2>
  <div class="pid-row">
    <div class="pid-field">
      <label>Kp</label>
      <input type="number" id="kp" value="20.0" step="0.01"> </div>
    <div class="pid-field">
      <label>Ki</label>
      <input type="number" id="ki" value="5.00" step="0.01">
    </div>
    <div class="pid-field">
      <label>Kd</label>
      <input type="number" id="kd" value="0.5" step="0.01"> </div>
  </div>

  <button onclick="sendPID()">Speichern</button>
  <p id="pid-status"></p>

  <script>
    const canvas = document.getElementById("joystick");
    const ctx = canvas.getContext("2d");

    const cx = canvas.width / 2;
    const cy = canvas.height / 2;
    const radius = 100;
    const knobRadius = 30;

    let knobX = cx;
    let knobY = cy;
    let active = false;
    let joyX = 0;
    let joyY = 0;
    let currentOffset = 0.0;

    function drawJoystick() {
      ctx.clearRect(0, 0, canvas.width, canvas.height);

      ctx.beginPath();
      ctx.arc(cx, cy, radius, 0, Math.PI * 2);
      ctx.fillStyle = "#404040";
      ctx.fill();
      ctx.strokeStyle = "#606060";
      ctx.lineWidth = 2;
      ctx.stroke();

      ctx.strokeStyle = "#606060";
      ctx.lineWidth = 1;
      ctx.beginPath();
      ctx.moveTo(cx - radius, cy);
      ctx.lineTo(cx + radius, cy);
      ctx.stroke();
      ctx.beginPath();
      ctx.moveTo(cx, cy - radius);
      ctx.lineTo(cx, cy + radius);
      ctx.stroke();

      ctx.beginPath();
      ctx.arc(knobX, knobY, knobRadius, 0, Math.PI * 2);
      ctx.fillStyle = active ? "#909090" : "#707070";
      ctx.fill();
    }

    function updateKnob(x, y) {
      const dx = x - cx;
      const dy = y - cy;
      const dist = Math.sqrt(dx * dx + dy * dy);
      const maxDist = radius - knobRadius;
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

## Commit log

2026-05-11 Add feedback on ESP32 and L298n in README
2026-05-28 Add self-balancing robot code for ESP32
2026-05-28 Rename Schematic_Self-balancing-robot_2026-05-15.pdf to Schaltkreise/Schematic_Self-balancing-robot_2026-05-15.pdf
2026-06-07 Code angepasst
    [Grundkörper.3mf, robot_data.csv]
2026-06-07 Kommentare ergänzt und Bilder hochgeladen
2026-06-09 letzte Änderungen
    [Sturz.csv, robot_data.csv]
2026-06-09 Fotos und Videos
2026-06-13 zweite powerpoint variante
2026-06-13 an powerpoint weitergerabeitet
2026-06-16 kleine Änderungen an der Präsentation vorgenommen
